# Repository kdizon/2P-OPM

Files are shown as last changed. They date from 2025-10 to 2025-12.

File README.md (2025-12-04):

# 2P-OPM: Two-photon oblique plane microscope

Open CAD, control code, reconstruction, data, and videos for the 2P-OPM instrument.

## Contents
- Opto-mechanical CAD (Inventor + STEP/STL): **[CAD/](./CAD)**
- Instrument control/acquisition (FastMC): **[code/control/](./code/control)**
- GPU-accelerated volume reconstruction: **[code/reconstruction/](./code/reconstruction)**
- Representative image datasets: **[data/](./data)**
- Associated videos: **[movies/](./movies)**

## Citation
If you use the 2P-OPM hardware design, code, data, or videos, please cite:

K. Keomanee-Dizon, Y. Clenman, A. Duran, S. Ryabichko, P. Hansen, T. Borjigin, R. Thornton, J. E. Toettcher, & H. M. McNamara.  
**Depth-enhanced molecular imaging with two-photon oblique plane microscopy.**  
arXiv:2511.09462 [physics.optics] (2025). https://doi.org/10.48550/arXiv.2511.09462

## Licensing
- Code: [BSD-3-Clause](./LICENSE)
- CAD: [CERN-OHL-P v2.0](./CAD/LICENSE)
- Data: [CC BY 4.0](./data/LICENSE)
- Videos: [CC BY 4.0](./movies/LICENSE)

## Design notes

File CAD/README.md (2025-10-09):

# 2P-OPM hardware
Hardware files for the 2P-OPM.

## Description
This repository contains the opto-mechanical CAD (AutoDesk Inventor) model for the 2P-OPM system. Files are organized in directories for each vendor, with subassemblies for various parts of the microscope.

© 2025 Kevin Keomanee-Dizon. Licensed under CERN-OHL-P v2.0; see [LICENSE](./LICENSE).

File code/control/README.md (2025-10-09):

# FastMC — Fast multi-camera acquisition for 2P-OPM

FastMC provides NI-DAQ–driven timing for one or more PCO Edge cameras (validated with up to 3), the OPM galvo, and optional LED control, with Micro-Manager used as the **viewer only**. The hardware timing and limits come from `FastMC_core.py`; `FastMC.py` is the user-editable runner/config.

---

## Files
- **`FastMC_core.py`** — core NI-DAQ functions and timing logic (galvo AO, LED DO, camera triggers, limits). _Do not modify._
- **`FastMC.py`** — edit parameters here (2D/3D, exposure, ROI, z-range, LED mode) and run.

## Requirements
- Windows with **NI-DAQmx** and a compatible NI device (e.g., Dev1).
- **PCO Edge** cameras (CL) with SDK/driver accessible to Python.
- Python packages: `nidaqmx`, `numpy`, `scipy`, `matplotlib`, `tkinter` (stdlib), and your PCO camera Python module (`pco`).  
- Micro-Manager (as a viewer only).

---

## Quick start
1. Open **`FastMC.py`** and set parameters (see inline comments):  
   - `multi_d=False` for **2D** (stacks = frames) **or** `True` for **3D** (stacks = volumes).  
   - `num_stacks`, `stack_delay_time`, `exposure_time`, `readout_mode="fast"|"slow"`.  
   - For 3D: set `z_start`, `z_end`, `z_step`.  
   - Optional LED control via `led_trigger="hardware"|"software_fraction"|"software_time"`, plus `led_stack_fraction_on` or `led_time_on`/`led_frequency`.
2. Run:
   ```bash
   python FastMC.py

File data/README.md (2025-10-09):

# Datasets (2P-OPM)

All datasets are **background-subtracted** and provided as **representative subsets**.

## Beads (PSF benchmarking)
- **Path:** `data/beads/Fig_S9/`
- **Type:** Reconstructed volume
- **File:** `recon_BS.tif`
- **Used in:** Fig. S9
- **Notes:** 0.08667 µm isotropic voxels

## Flies — dual-color transcription imaging
- **Path:** `data/flies/Fig_5a/`
- **Type:** Reconstructed volume (2 channels)
- **Files:**  
  `recon_bcd-eGFP_BS.tif`  
  `recon_hb-MS2-MCP-mCherry_BS.tif`
- **Used in:** Fig. 5a
- **Notes:** channels correspond to bcd-eGFP and hb-MS2/MCP-mCherry; 0.17334 µm isotropic voxels

## Flies — single-molecule imaging
- **Path:** `data/flies/Fig_5e-h/`
- **Type:** Raw single-molecule time lapse
- **File:** `Raw_BS.tif`
- **Used in:** Fig. 5e–h
- **Notes:** 0.17334 µm pixel size; 20 Hz frame rate

---

### Format
- **TIFF** stacks
- Acquisition & processing details are described in the manuscript (Methods and Imaging conditions).

© 2025 Kevin Keomanee-Dizon. Licensed under CC BY 4.0; see [LICENSE](./LICENSE).

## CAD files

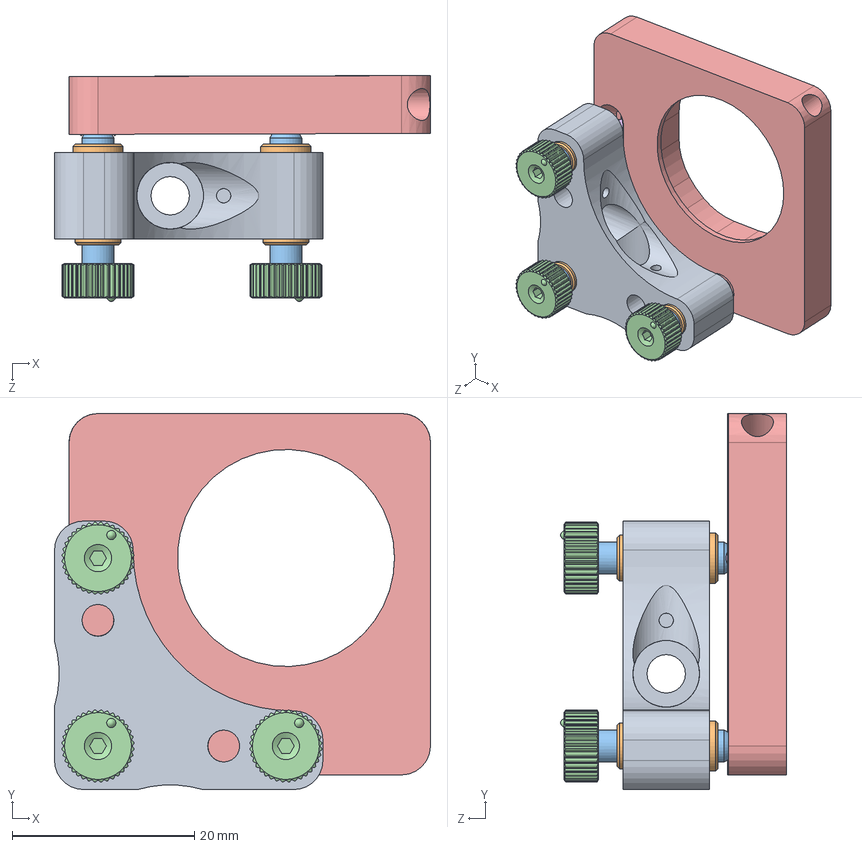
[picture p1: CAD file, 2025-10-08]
CAD/1P Laser Combiner/newfocus_9884_pint_size_corner_mount.sldasm
41.3 x 41.3 x 24.8 mm

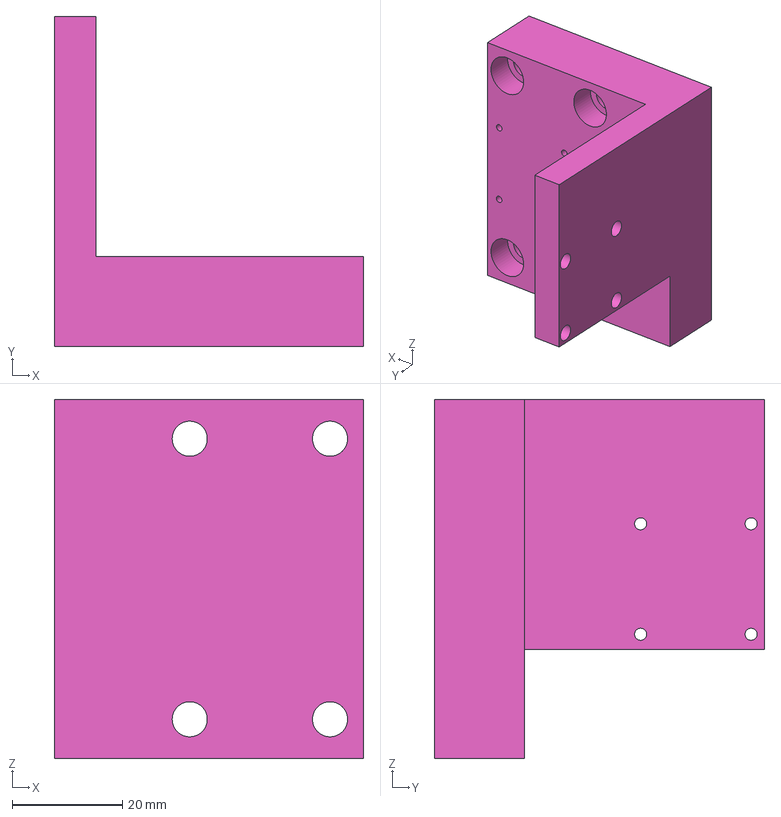
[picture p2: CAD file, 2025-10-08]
CAD/1P Laser Combiner/beam steering subassy mounting bracket.stp
56.0 x 59.8 x 65.0 mm

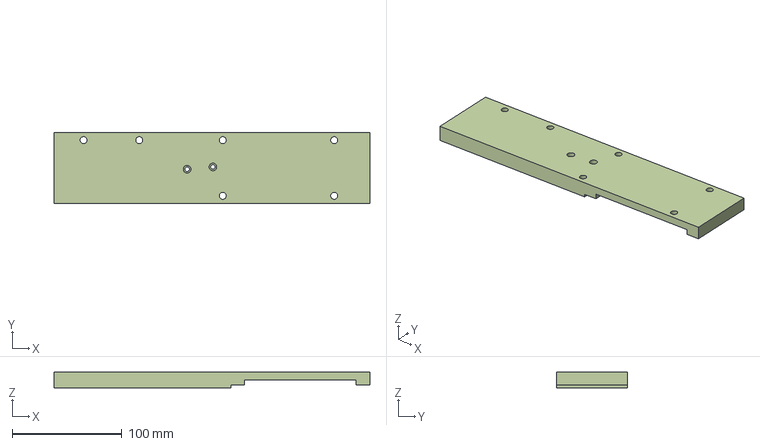
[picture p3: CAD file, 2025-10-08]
CAD/1P Laser Combiner/OBIS laser subassy shortened baseplate.stp
288.3 x 65.0 x 14.3 mm

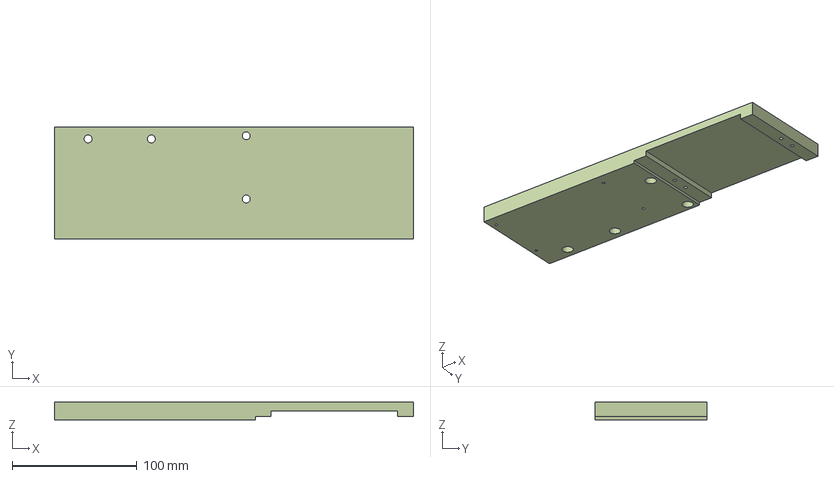
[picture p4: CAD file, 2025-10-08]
CAD/1P Laser Combiner/Sapphire laser subassy shortened baseplate.stp
288.3 x 90.0 x 14.3 mm

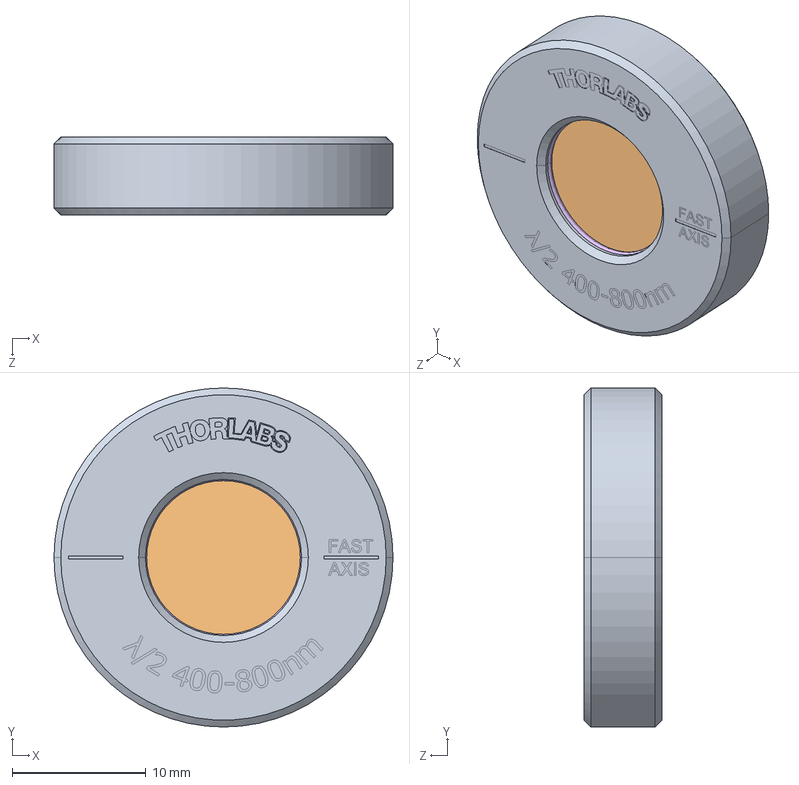
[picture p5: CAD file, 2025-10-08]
CAD/1P Laser Combiner/AHWP05M-600-Step.step
25.4 x 25.4 x 5.84 mm

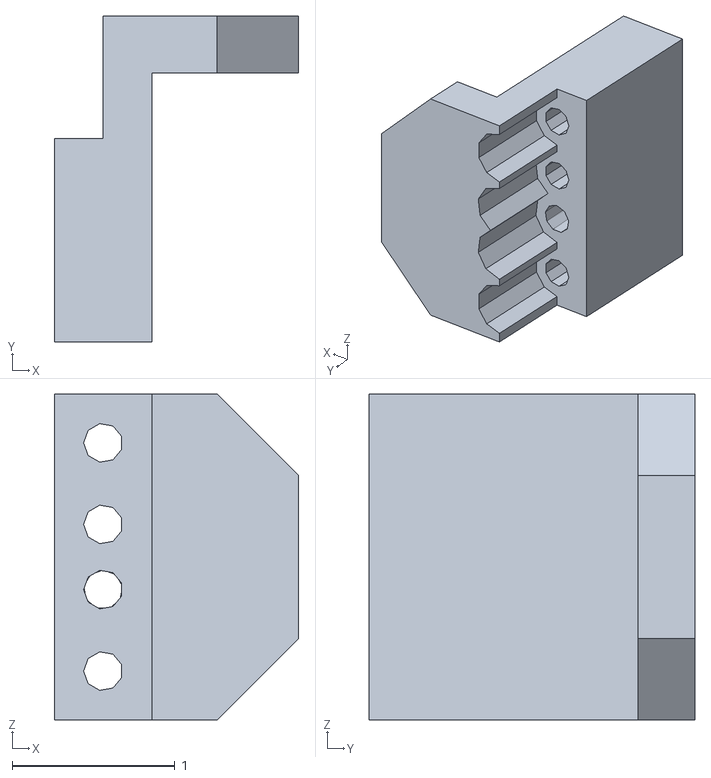
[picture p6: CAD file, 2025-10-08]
CAD/Custom 3D Printed Parts/galvo_stop.stl
1.50 x 2.00 x 2.00

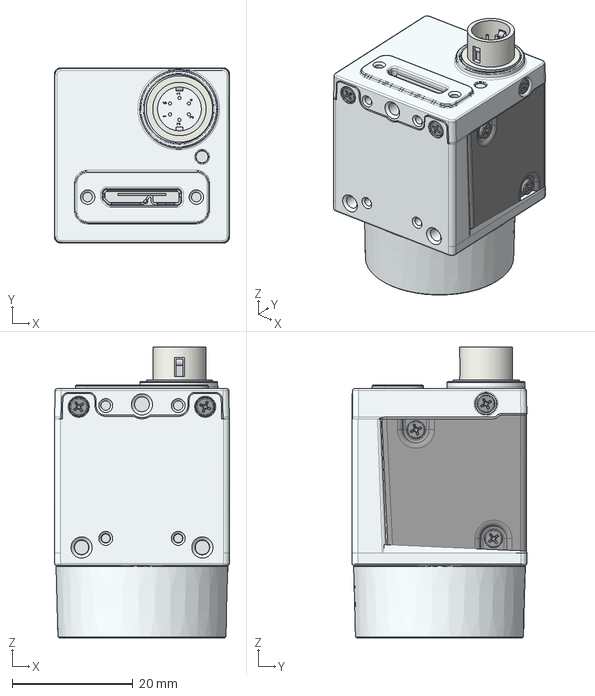
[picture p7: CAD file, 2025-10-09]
CAD/Imported Components/Basler/Basler ace USB3 C-Mount v02.STP
29.0 x 29.0 x 48.2 mm

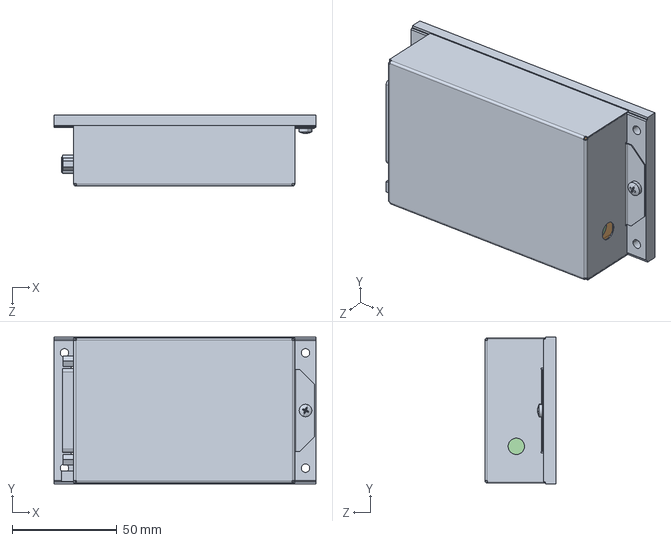
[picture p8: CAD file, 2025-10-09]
CAD/Imported Components/Coherent/Sapphire LP Laser Head.STEP
125.0 x 70.0 x 34.0 mm

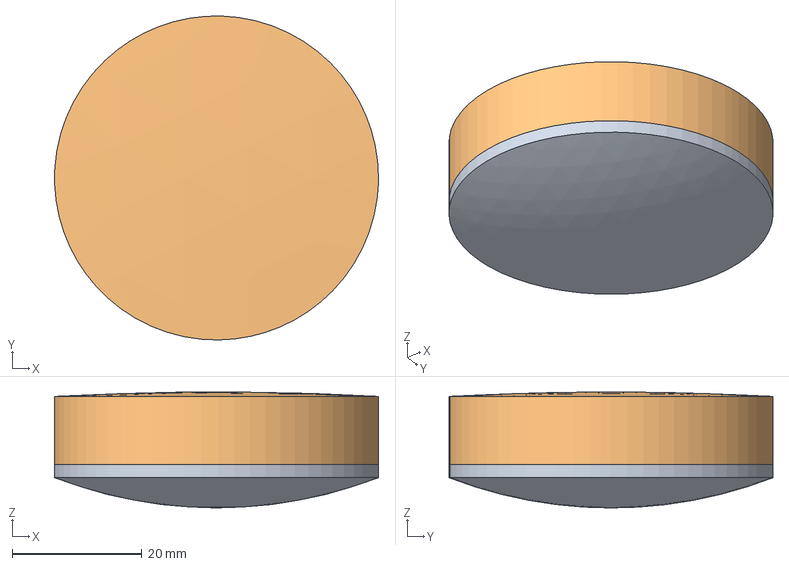
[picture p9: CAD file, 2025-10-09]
CAD/Imported Components/Edmund/EO_49390.stp
50.0 x 50.0 x 17.9 mm

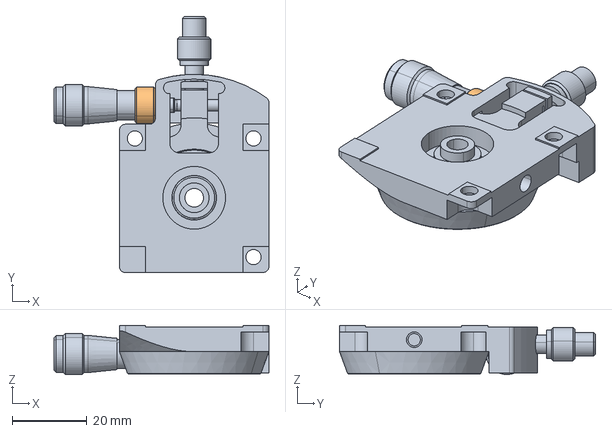
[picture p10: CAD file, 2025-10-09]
CAD/Imported Components/Newport/Newport-RS40.stp
57.5 x 68.5 x 13.1 mm

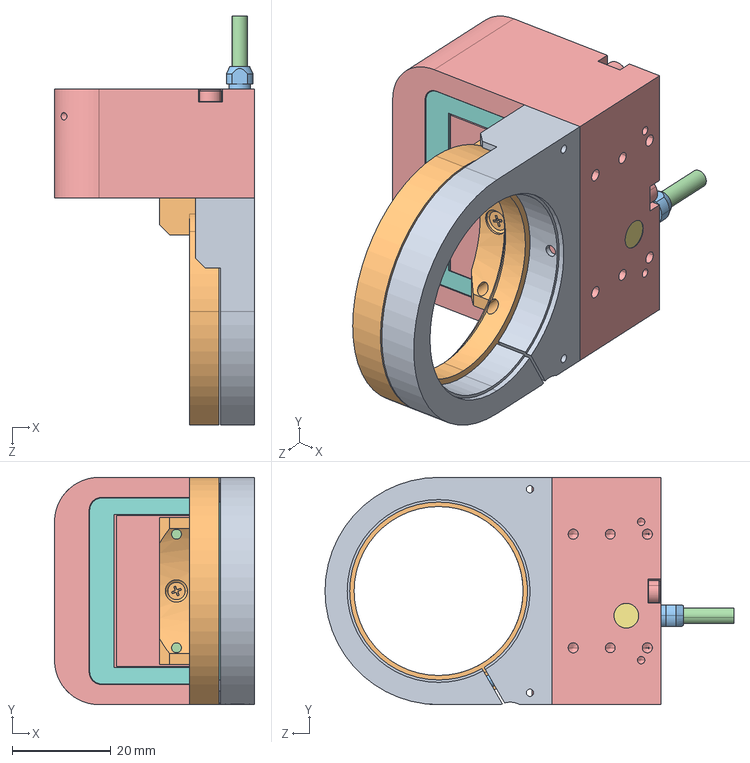
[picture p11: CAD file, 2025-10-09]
CAD/Imported Components/PI/P-725.xCA.STEP
40.5 x 46.0 x 82.8 mm

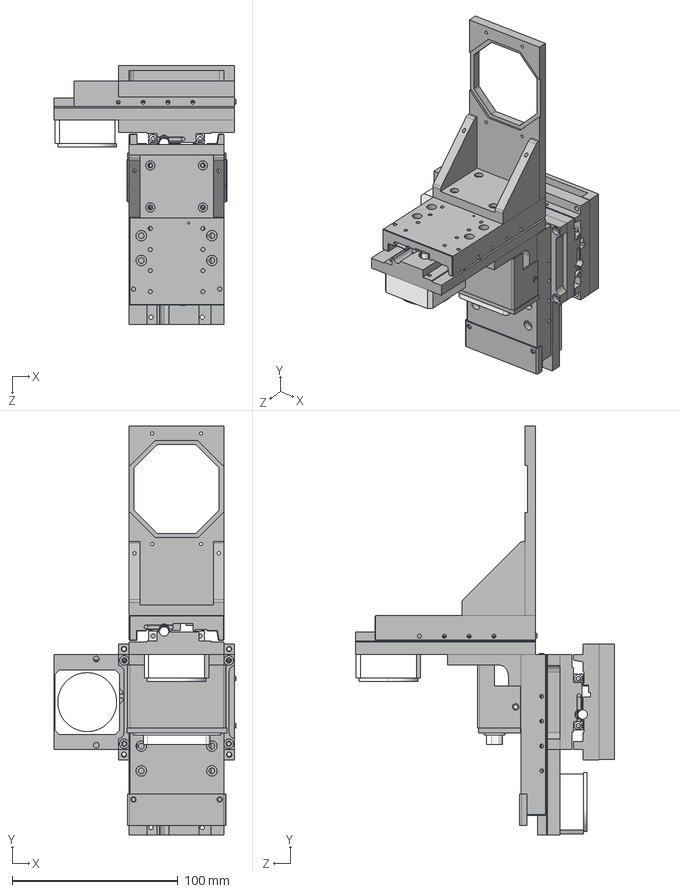
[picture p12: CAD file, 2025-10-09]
CAD/Imported Components/Sutter/MP285 3DMS SIMPLE.STEP
109.6 x 246.8 x 156.5 mm

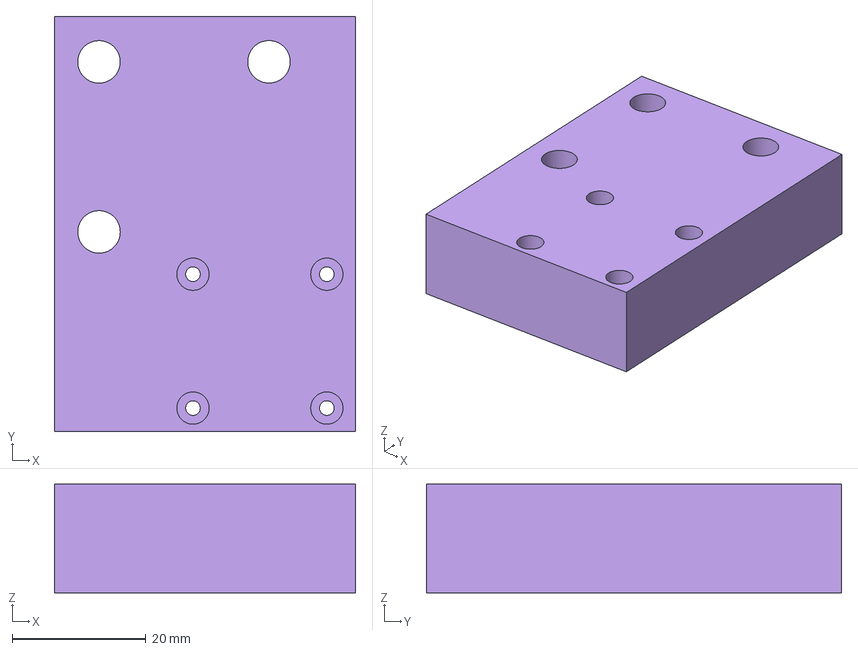
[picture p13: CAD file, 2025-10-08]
CAD/1P Laser Combiner/baseplate for combined beam steering mirror.stp
45.0 x 62.0 x 16.2 mm

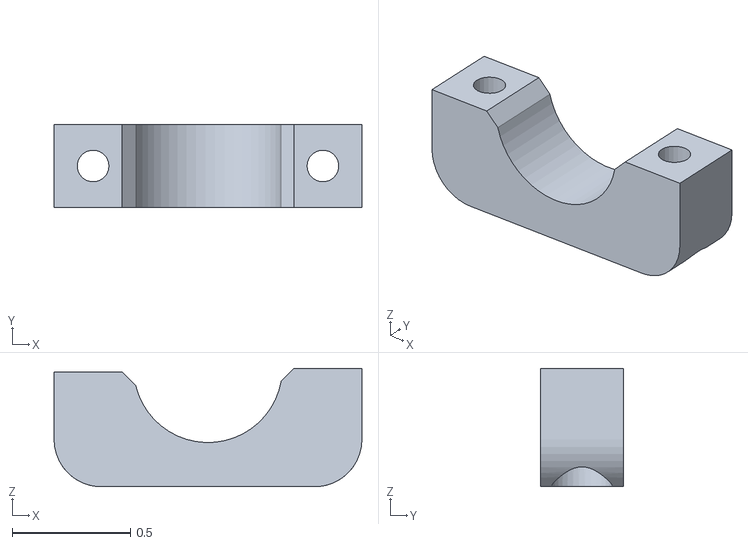
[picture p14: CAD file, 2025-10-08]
CAD/Custom 3D Printed Parts/20-1531-001_ResGalvoClamp.obj
1.30 x 0.35 x 0.5

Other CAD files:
CAD/Custom Parts Linked With Drawings/ResGalvoMount_base_plate.stp
CAD/Imported Components/Coherent/Sapphire LP Heatsink with dowel pins.STEP
CAD/Imported Components/Edmund/EO_85678.step
CAD/Imported Components/Newport/Newport-SA2-11.stp
CAD/1P Laser Combiner/003550_2.ipt
CAD/1P Laser Combiner/903279.ipt
CAD/1P Laser Combiner/903812-08.ipt
CAD/1P Laser Combiner/903893.ipt
CAD/1P Laser Combiner/903896.ipt
CAD/1P Laser Combiner/903898-01.ipt
CAD/1P Laser Combiner/9884PLT_ASM.iam
CAD/1P Laser Combiner/AA Optoelectronc AOTF-nc.ipt
CAD/1P Laser Combiner/AA Optoelectronc AOTF-nc.sldprt
CAD/1P Laser Combiner/AHWP05M-600-Step.ipt
CAD/1P Laser Combiner/Drawings/OBIS laser subassy shortened baseplate.idw
CAD/1P Laser Combiner/Drawings/Sapphire laser subassy shortened baseplate.idw
CAD/1P Laser Combiner/Drawings/baseplate for combined beam steering mirror.idw
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

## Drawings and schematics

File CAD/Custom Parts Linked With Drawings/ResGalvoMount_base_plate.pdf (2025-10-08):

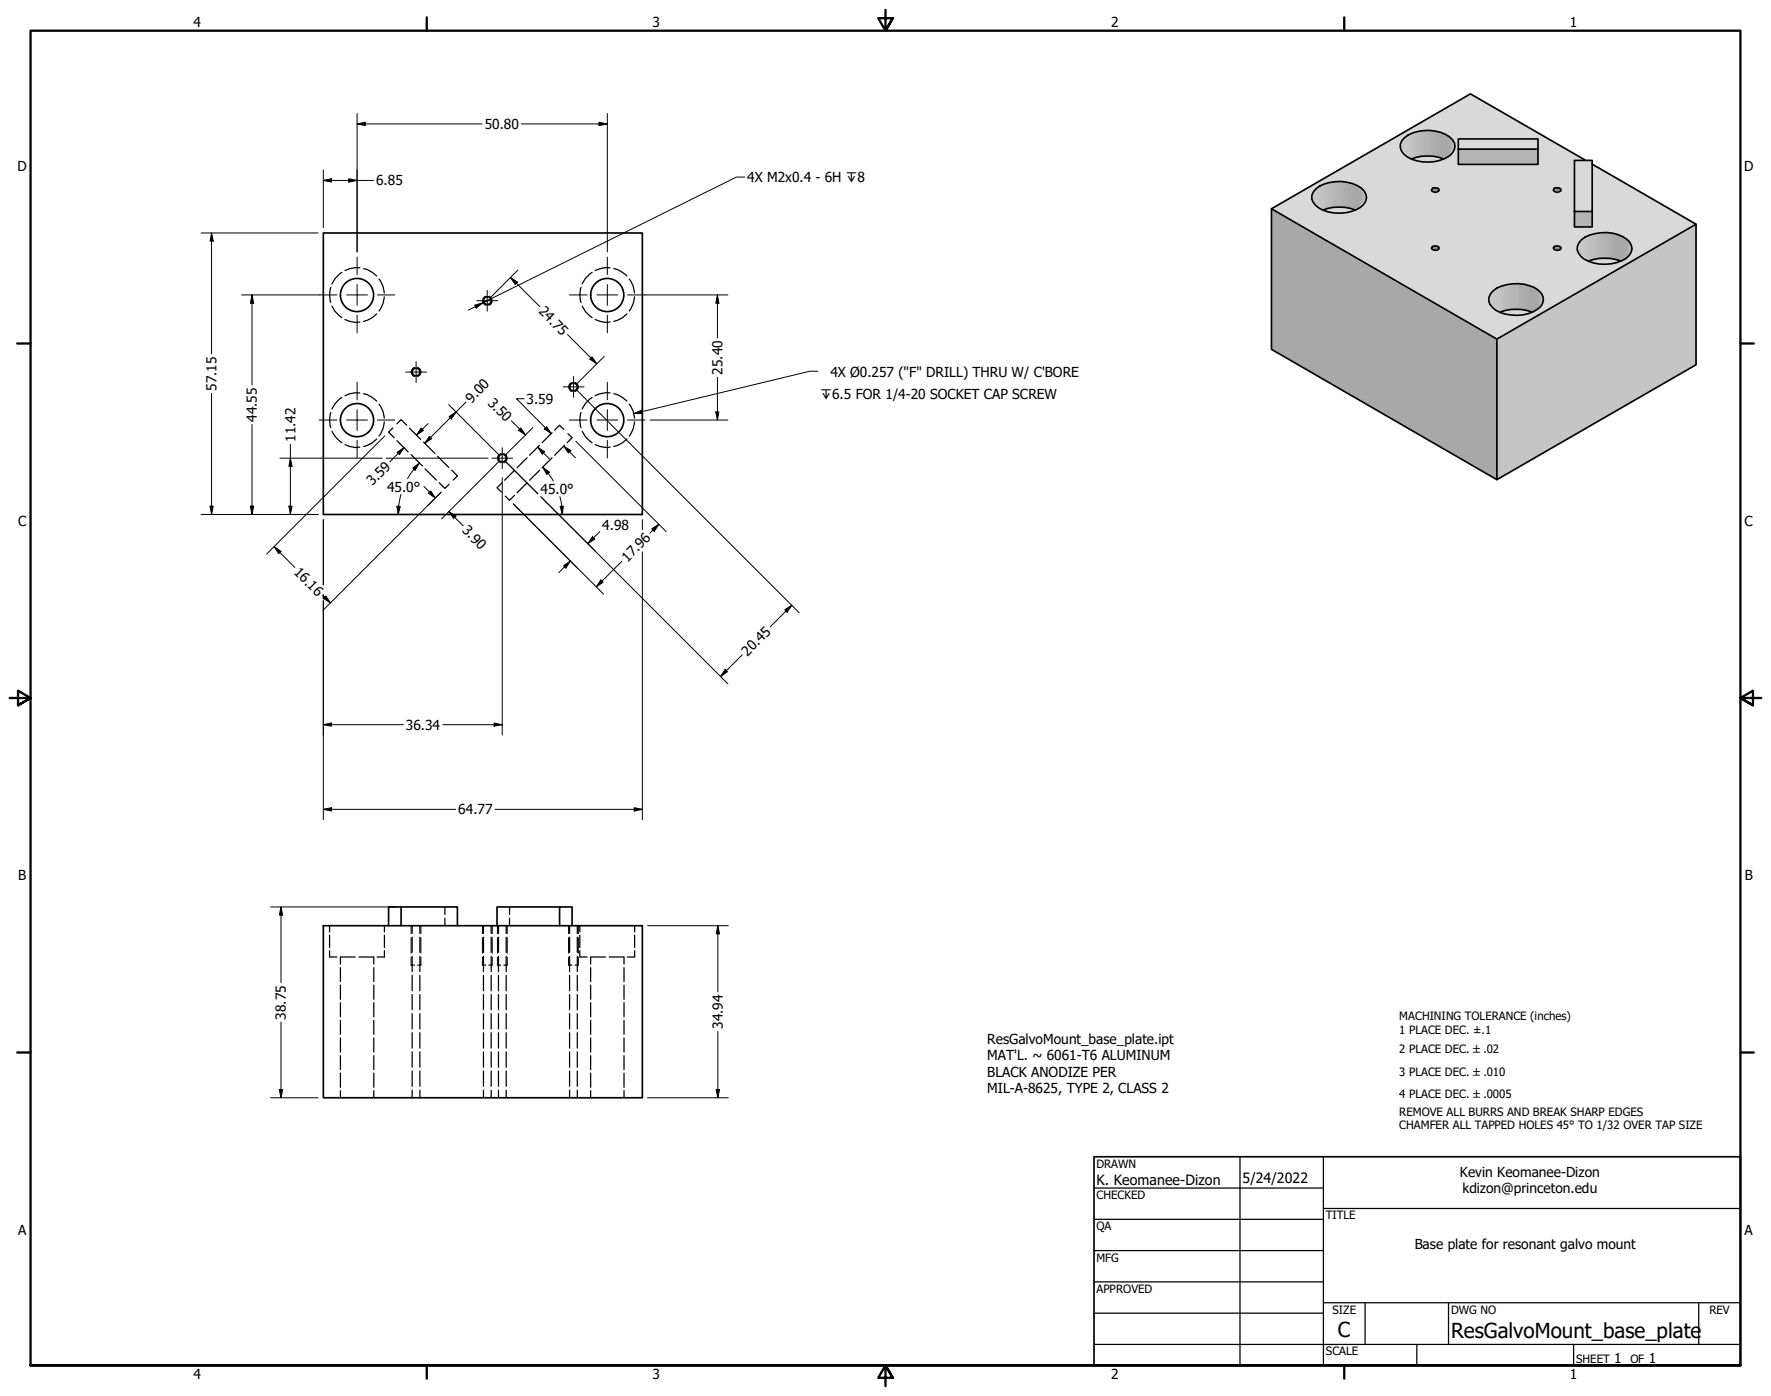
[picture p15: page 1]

4X Ø0.257 ("F" DRILL) THRU W/ C'BORE
6.5 FOR 1/4-20 SOCKET CAP SCREW

MACHINING TOLERANCE (inches)
1 PLACE DEC. ±.1
2 PLACE DEC. .02

ResGalvoMount_base_plate.ipt
MAT'L. ~ 6061-T6 ALUMINUM
BLACK ANODIZE PER
MIL-A-8625, TYPE 2, CLASS 2

4 PLACE DEC. .0005
REMOVE ALL BURRS AND BREAK SHARP EDGES
CHAMFER ALL TAPPED HOLES 45° TO 1/32 OVER TAP SIZE

DRAWN K. Keomanee-Dizon | 5/24/2022 | Kevin Keomanee-Dizon kdizon@princeton.edu

CHECKED

Base plate for resonant galvo mount

MFG

APPROVED

SIZE C | DWG NO ResGalvoMount_base_plate | REV

SCALE | | SHEET 1 OF 1

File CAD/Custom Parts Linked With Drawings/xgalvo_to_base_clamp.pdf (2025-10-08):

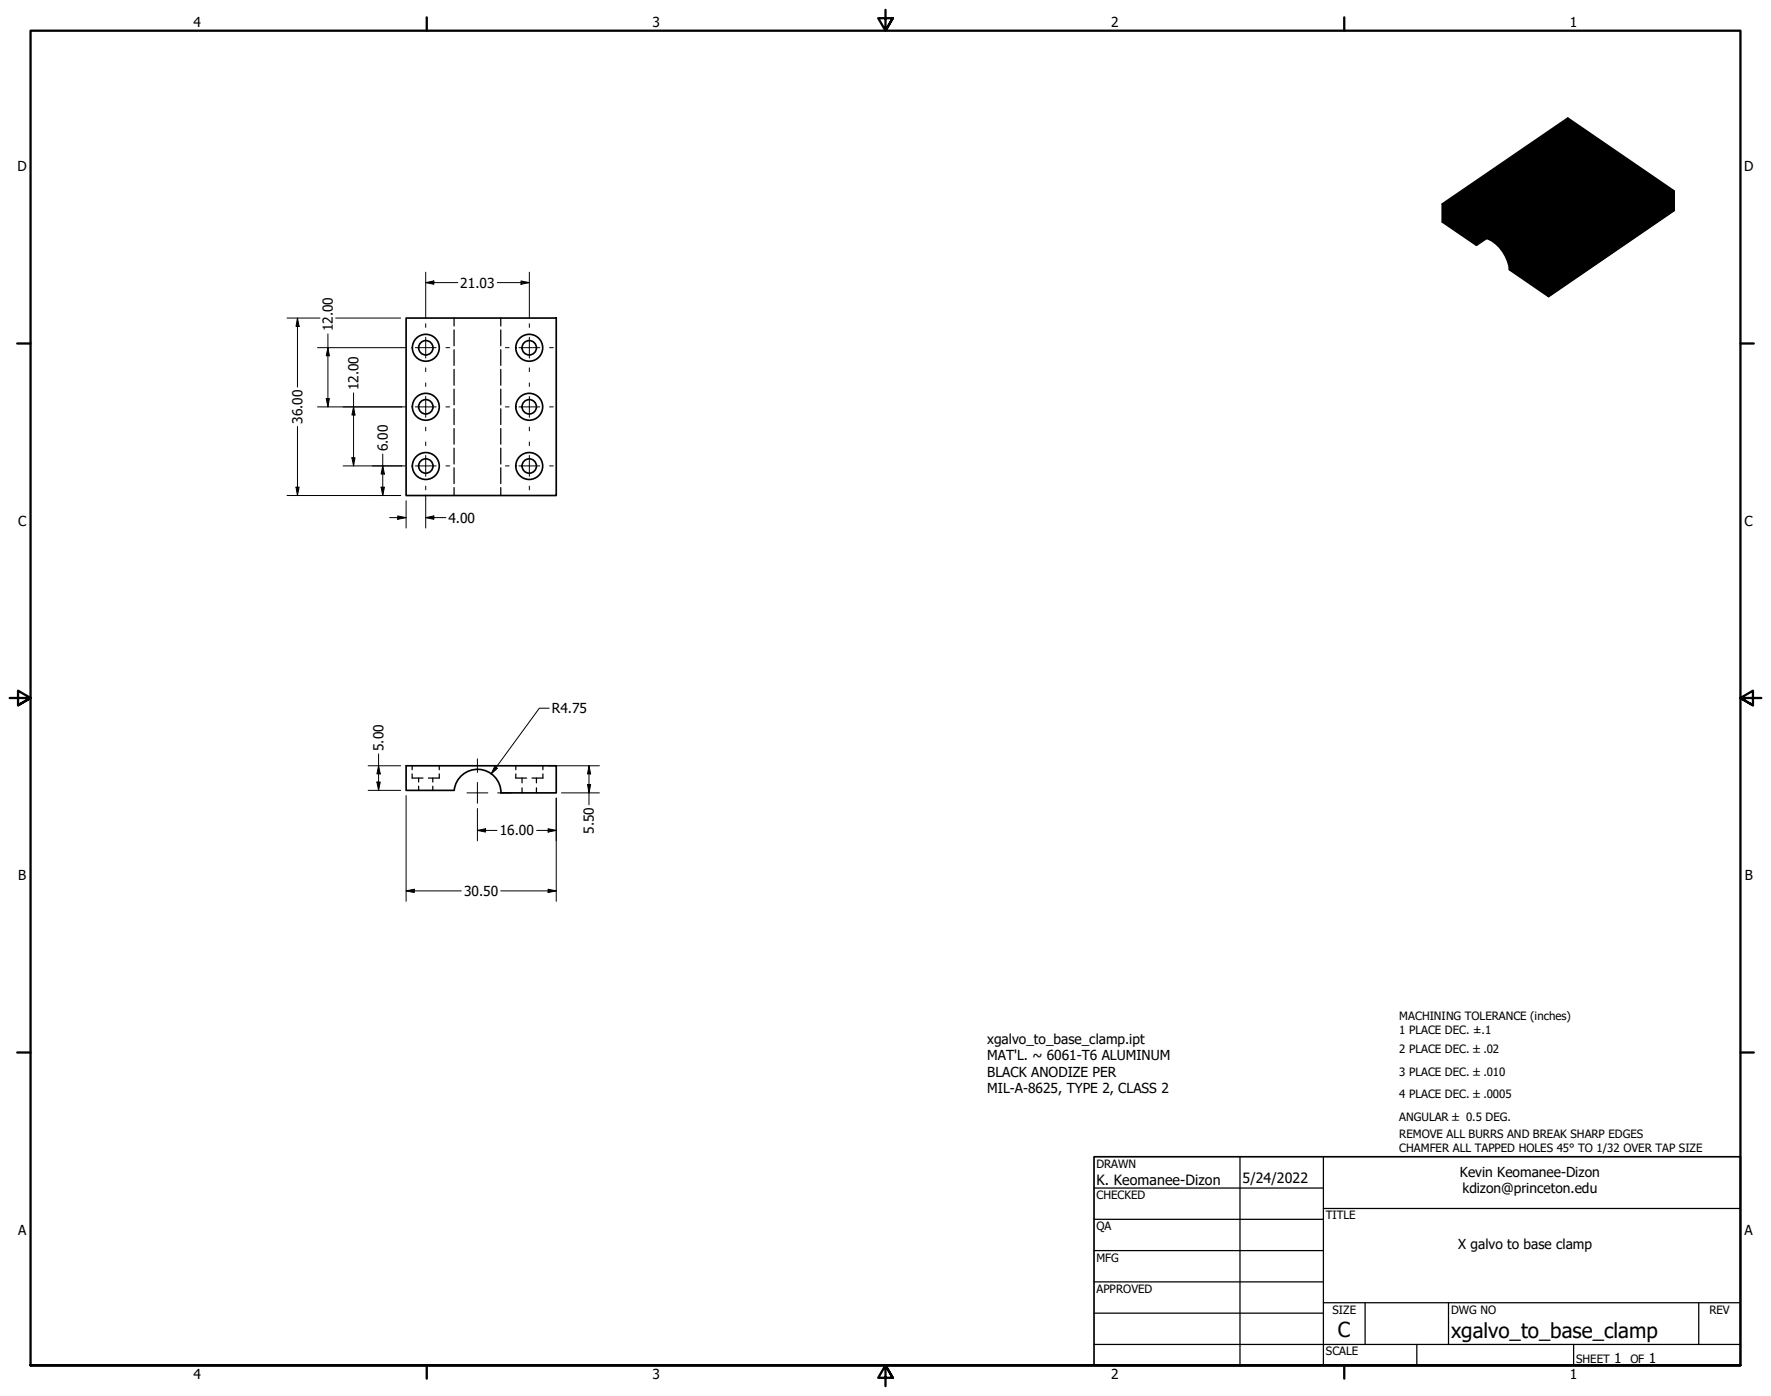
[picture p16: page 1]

MACHINING TOLERANCE (inches)
1 PLACE DEC. ±.1
2 PLACE DEC. .02

xgalvo_to_base_clamp.ipt
MAT'L. ~ 6061-T6 ALUMINUM
BLACK ANODIZE PER
MIL-A-8625, TYPE 2, CLASS 2

ANGULAR  0.5 DEG.
REMOVE ALL BURRS AND BREAK SHARP EDGES
CHAMFER ALL TAPPED HOLES 45° TO 1/32 OVER TAP SIZE

DRAWN K. Keomanee-Dizon | 5/24/2022 | Kevin Keomanee-Dizon kdizon@princeton.edu

CHECKED

X galvo to base clamp

MFG

APPROVED

SIZE C | DWG NO xgalvo_to_base_clamp | REV

SCALE | | SHEET 1 OF 1

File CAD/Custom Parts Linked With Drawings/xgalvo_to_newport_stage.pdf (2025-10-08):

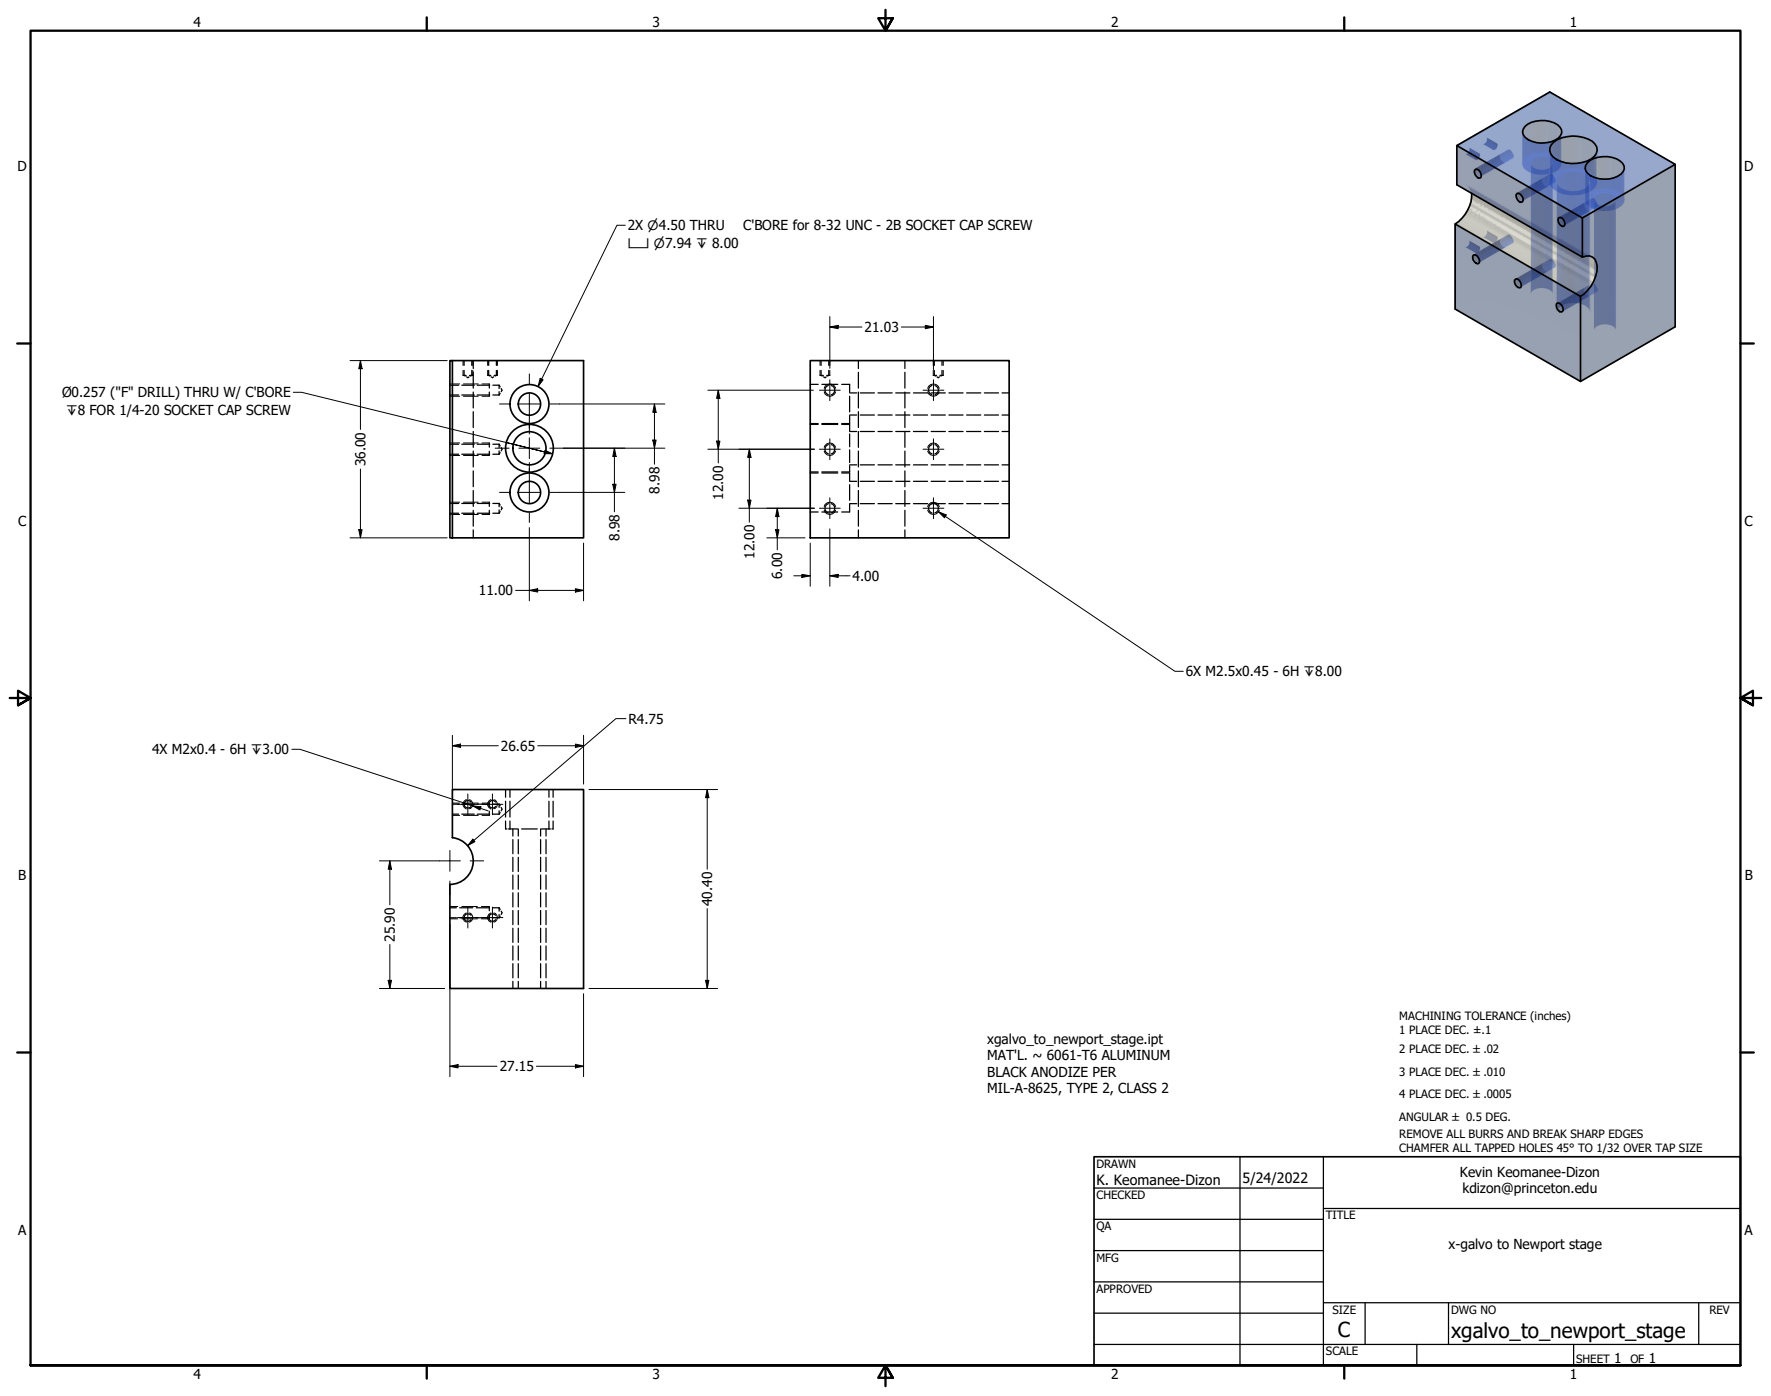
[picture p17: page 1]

C'BORE for 8-32 UNC - 2B SOCKET CAP SCREW

Ø0.257 ("F" DRILL) THRU W/ C'BORE
8 FOR 1/4-20 SOCKET CAP SCREW

MACHINING TOLERANCE (inches)
1 PLACE DEC. ±.1
2 PLACE DEC. .02

xgalvo_to_newport_stage.ipt
MAT'L. ~ 6061-T6 ALUMINUM
BLACK ANODIZE PER
MIL-A-8625, TYPE 2, CLASS 2

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

DRAWN K. Keomanee-Dizon | 5/24/2022 | Kevin Keomanee-Dizon kdizon@princeton.edu

CHECKED

x-galvo to Newport stage

MFG

APPROVED

SIZE C | DWG NO xgalvo_to_newport_stage | REV

SCALE | | SHEET 1 OF 1

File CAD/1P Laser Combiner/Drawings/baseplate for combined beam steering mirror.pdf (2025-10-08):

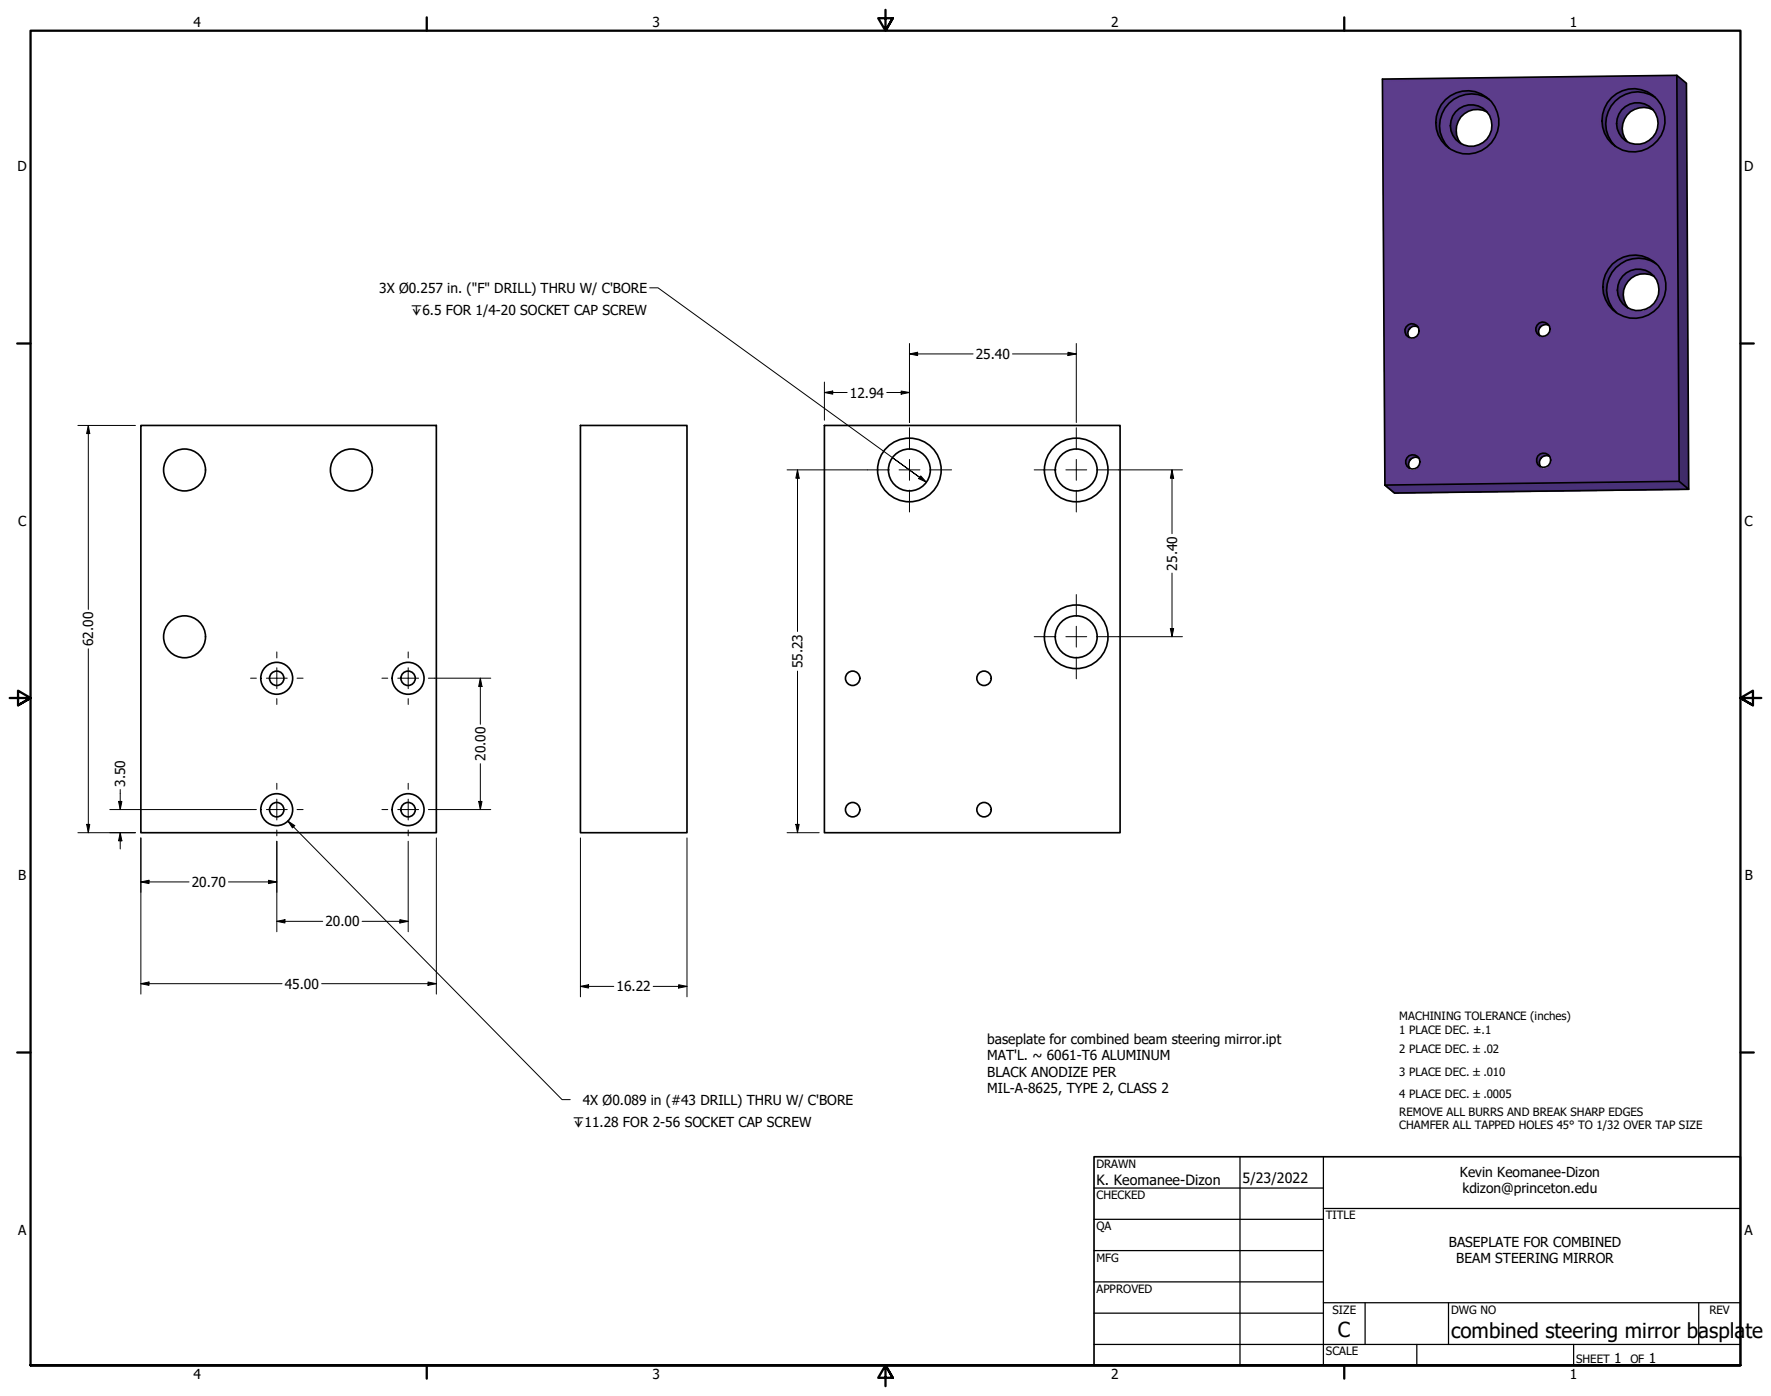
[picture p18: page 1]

3X Ø0.257 in. ("F" DRILL) THRU W/ C'BORE
6.5 FOR 1/4-20 SOCKET CAP SCREW

MACHINING TOLERANCE (inches)
1 PLACE DEC. ±.1
2 PLACE DEC. .02

baseplate for combined beam steering mirror.ipt
MAT'L. ~ 6061-T6 ALUMINUM
BLACK ANODIZE PER
MIL-A-8625, TYPE 2, CLASS 2

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

4X Ø0.089 in (#43 DRILL) THRU W/ C'BORE
11.28 FOR 2-56 SOCKET CAP SCREW

DRAWN K. Keomanee-Dizon | 5/23/2022 | Kevin Keomanee-Dizon kdizon@princeton.edu

CHECKED

BASEPLATE FOR COMBINED
BEAM STEERING MIRROR

MFG

APPROVED

SIZE C | DWG NO | REV

combined steering mirror basplate

SCALE | | SHEET 1 OF 1

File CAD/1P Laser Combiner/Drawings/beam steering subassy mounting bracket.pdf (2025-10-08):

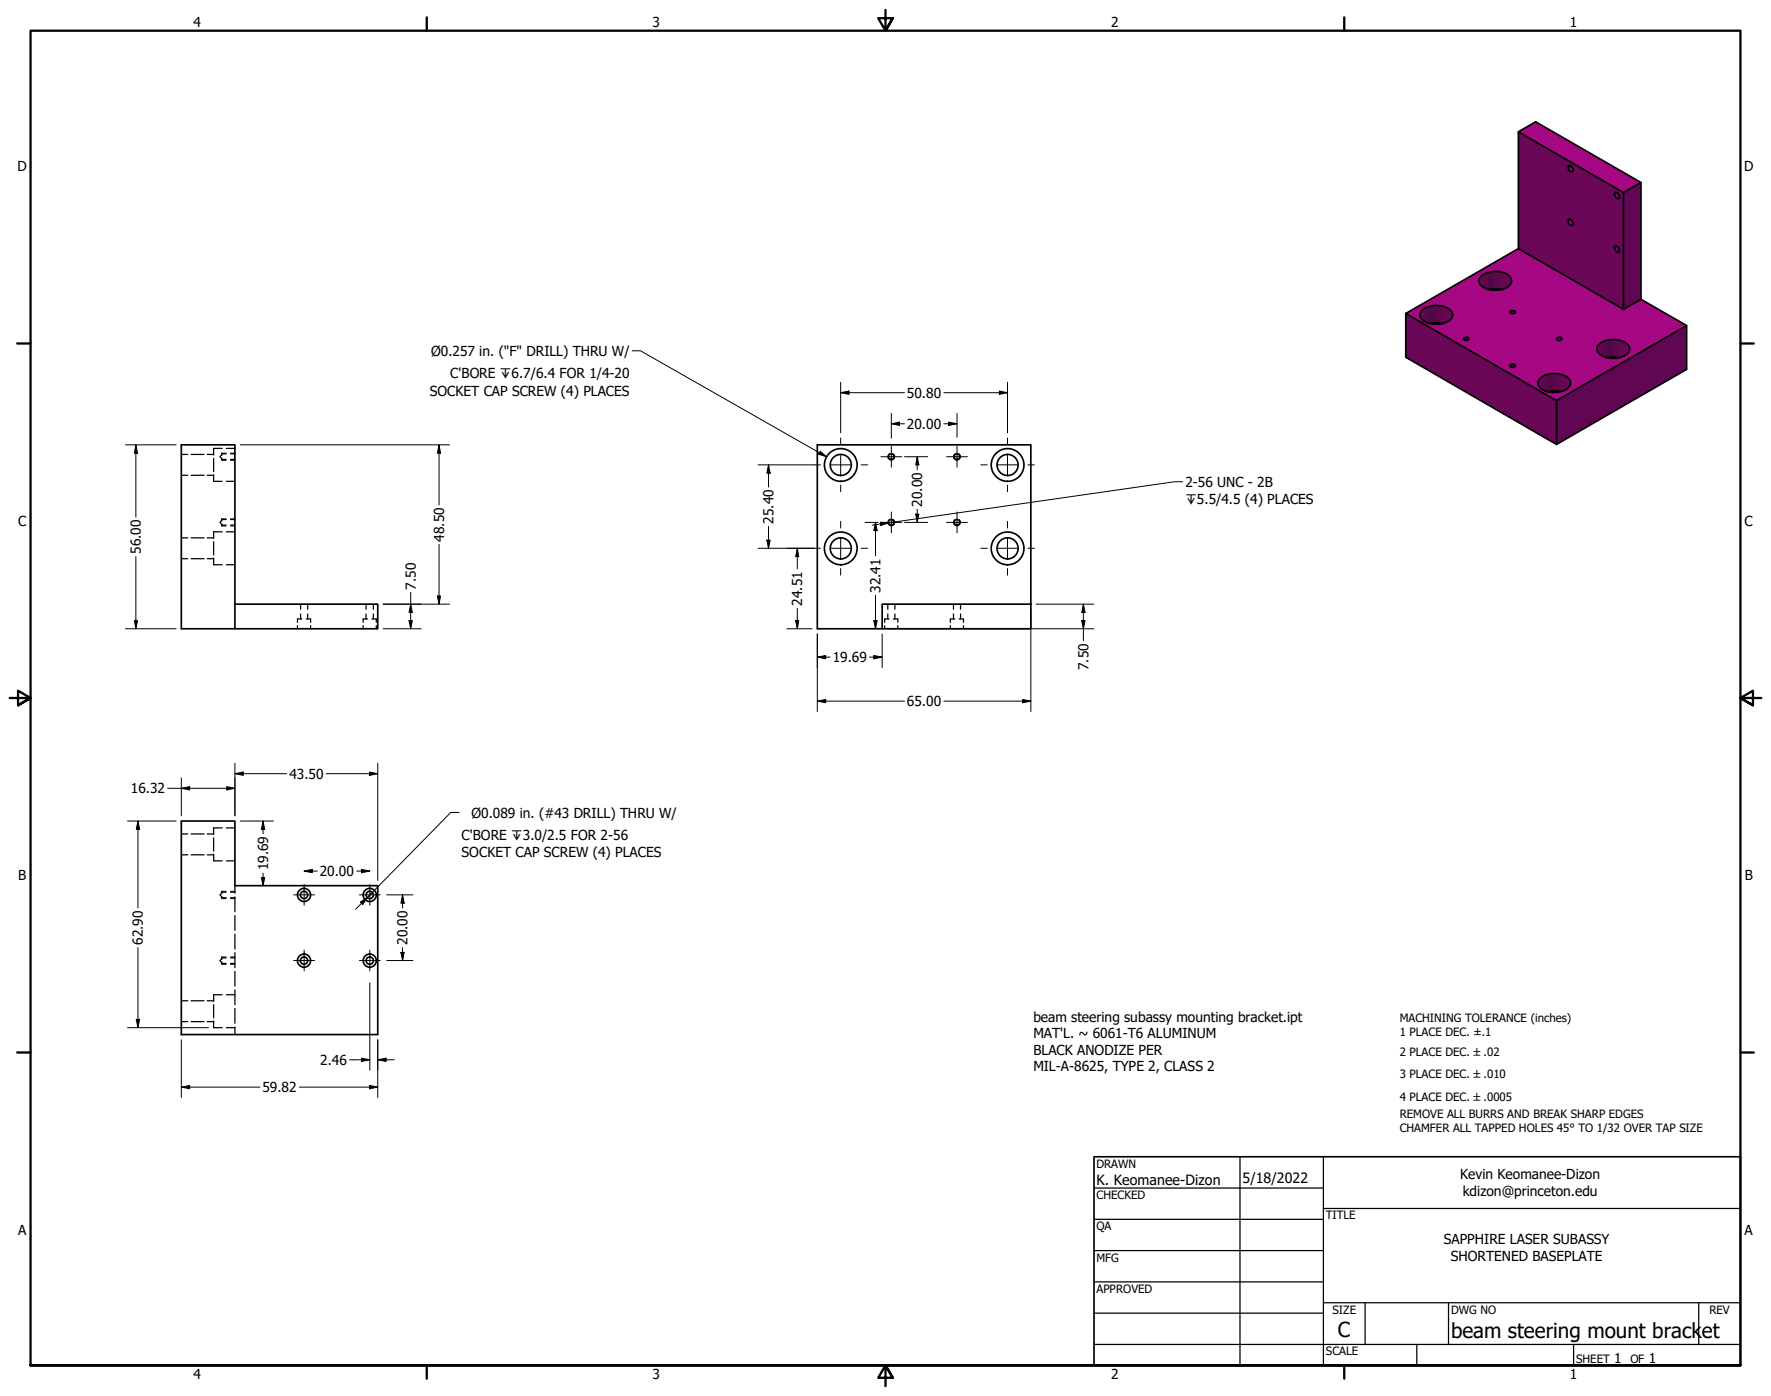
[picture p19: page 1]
2-56 UNC - 2B

Ø0.257 in. ("F" DRILL) THRU W/
C'BORE 6.7/6.4 FOR 1/4-20
SOCKET CAP SCREW (4) PLACES

Ø0.089 in. (#43 DRILL) THRU W/
C'BORE 3.0/2.5 FOR 2-56

beam steering subassy mounting bracket.ipt
MAT'L. ~ 6061-T6 ALUMINUM
BLACK ANODIZE PER
MIL-A-8625, TYPE 2, CLASS 2

MACHINING TOLERANCE (inches)
1 PLACE DEC. ±.1
2 PLACE DEC. .02

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

DRAWN K. Keomanee-Dizon | 5/18/2022 | Kevin Keomanee-Dizon kdizon@princeton.edu

CHECKED

SAPPHIRE LASER SUBASSY
SHORTENED BASEPLATE

MFG

APPROVED

SIZE C | DWG NO beam steering mount bracket | REV

SCALE | | SHEET 1 OF 1

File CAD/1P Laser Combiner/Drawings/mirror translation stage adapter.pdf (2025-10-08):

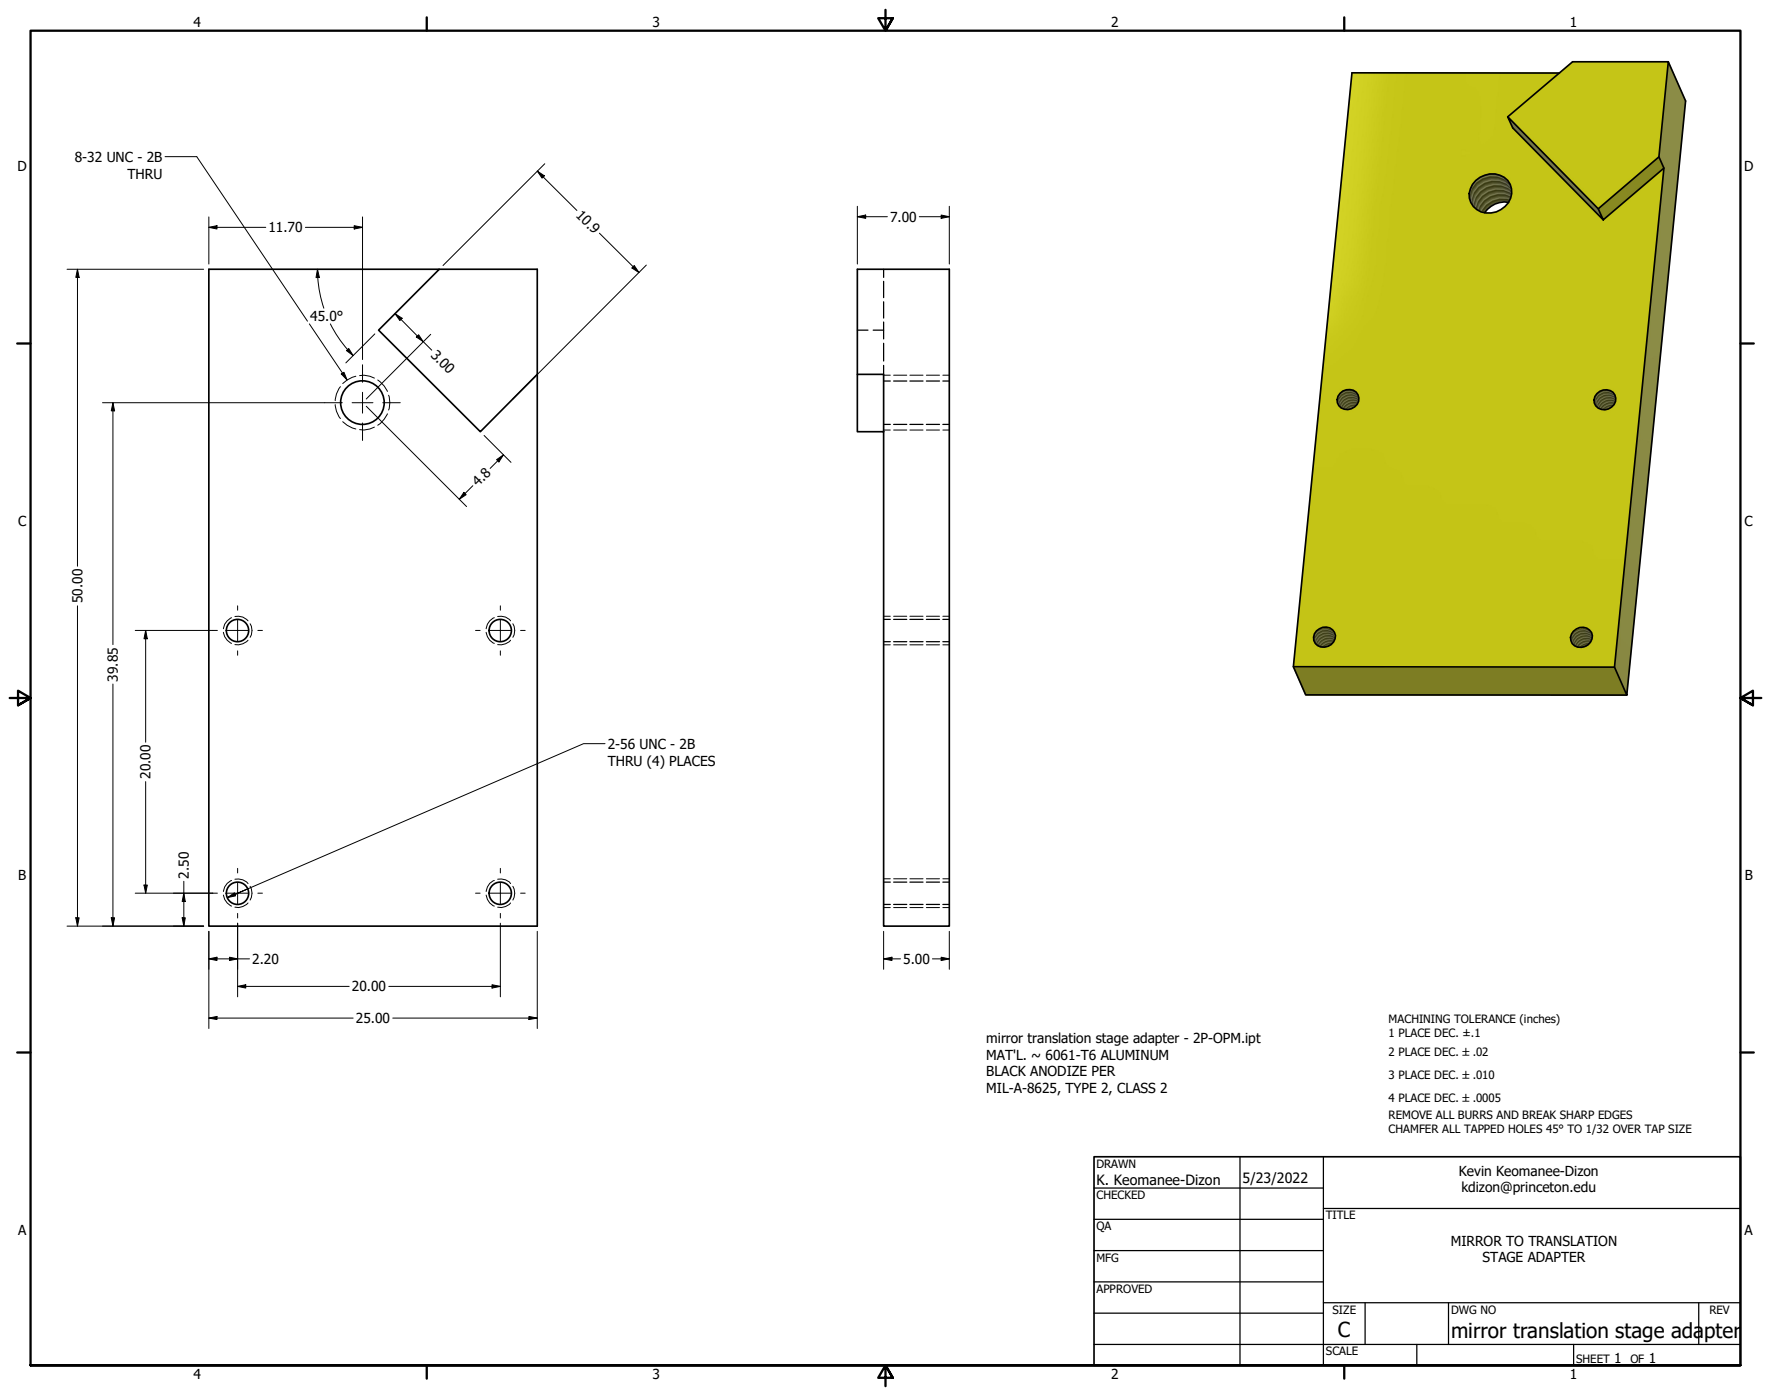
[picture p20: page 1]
2-56 UNC - 2B THRU (4) PLACES; 8-32 UNC - 2B

MACHINING TOLERANCE (inches)
1 PLACE DEC. ±.1
2 PLACE DEC. .02

mirror translation stage adapter - 2P-OPM.ipt
MAT'L. ~ 6061-T6 ALUMINUM
BLACK ANODIZE PER
MIL-A-8625, TYPE 2, CLASS 2

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

DRAWN K. Keomanee-Dizon | 5/23/2022 | Kevin Keomanee-Dizon kdizon@princeton.edu

CHECKED

MIRROR TO TRANSLATION
STAGE ADAPTER

MFG

APPROVED

SIZE C | DWG NO mirror translation stage adapter | REV

SCALE | | SHEET 1 OF 1

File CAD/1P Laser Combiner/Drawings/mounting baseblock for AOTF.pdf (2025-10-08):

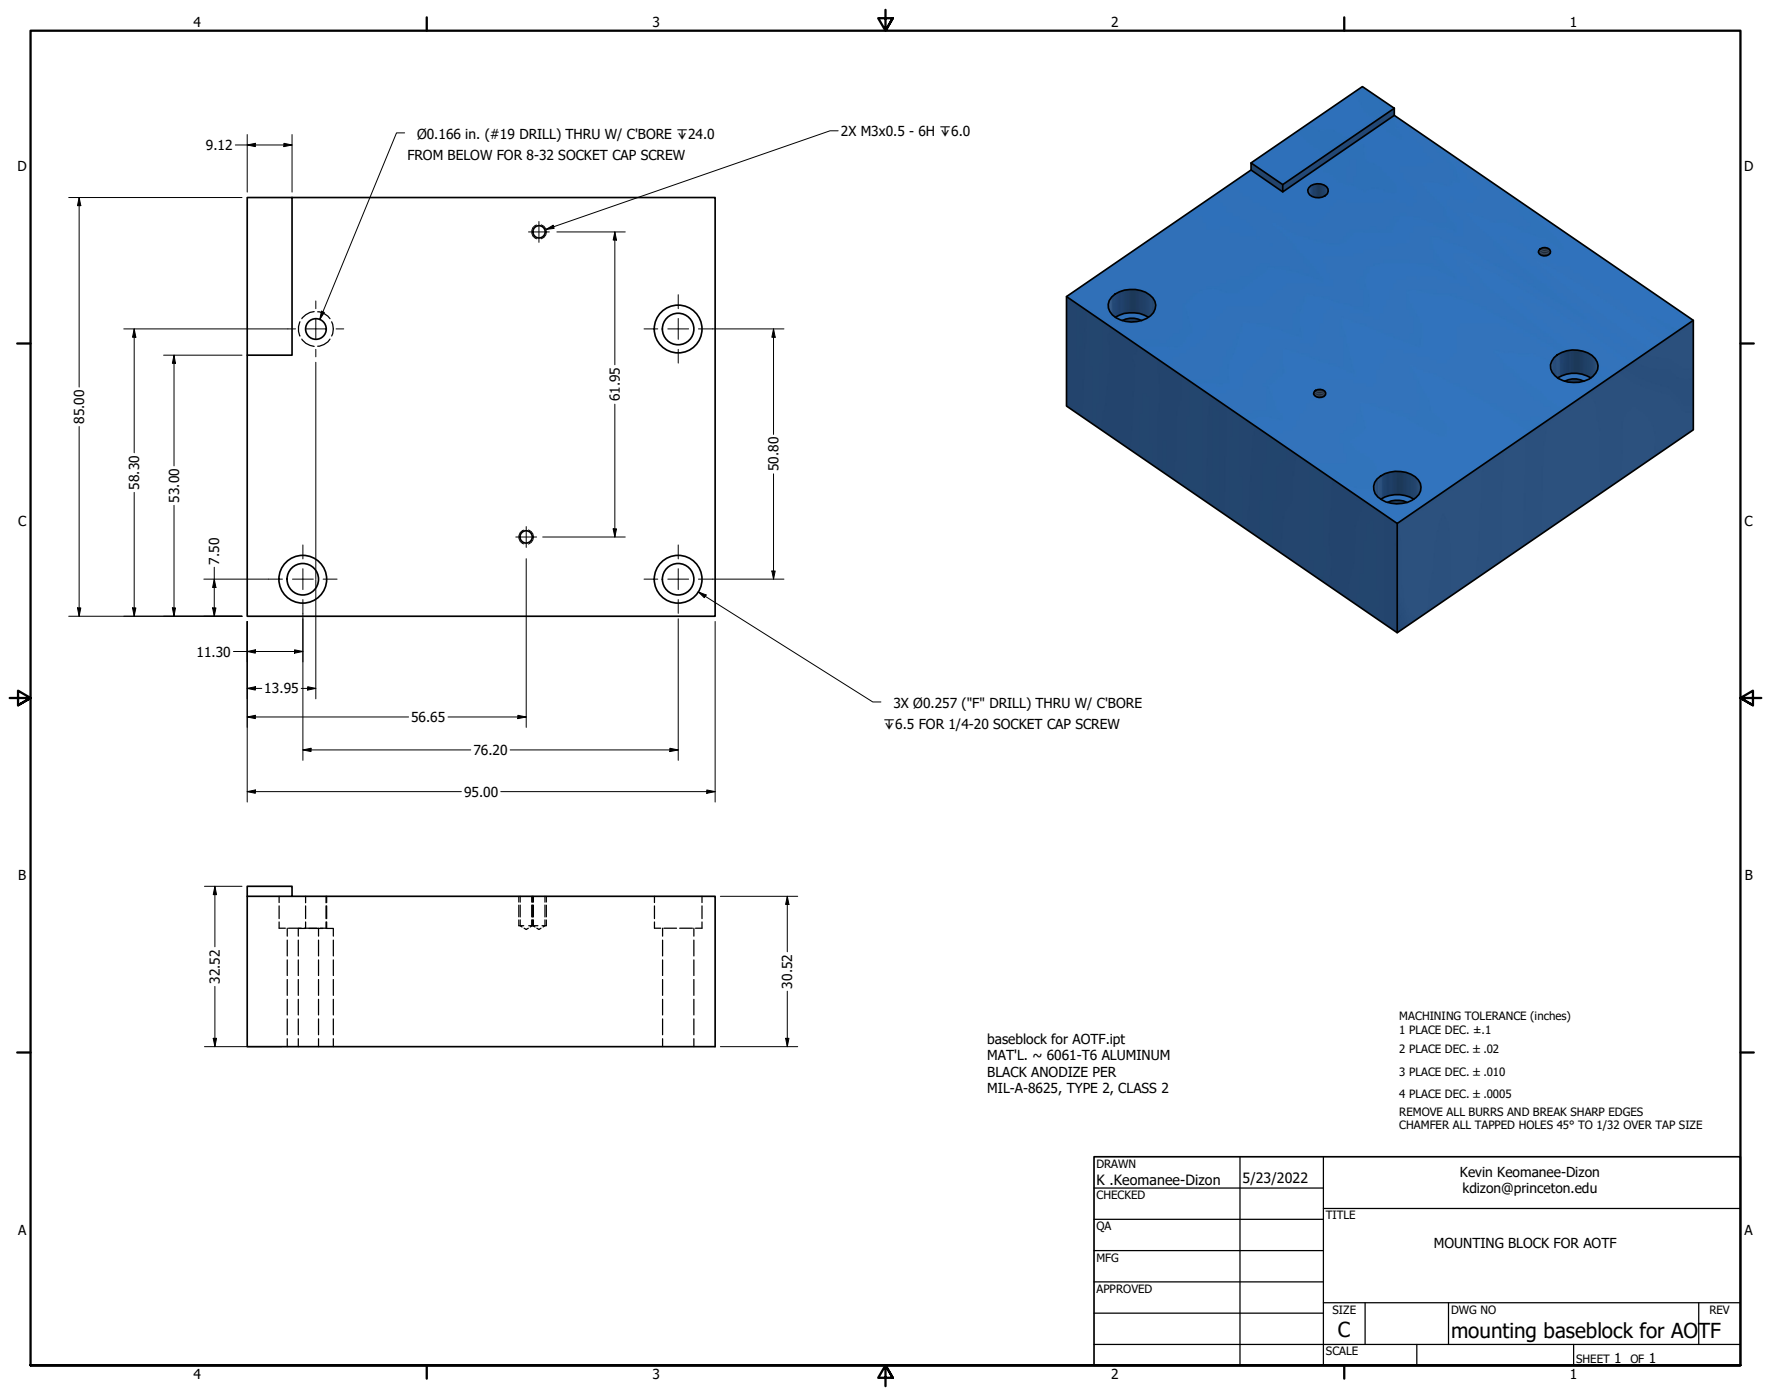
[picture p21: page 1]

FROM BELOW FOR 8-32 SOCKET CAP SCREW

3X Ø0.257 ("F" DRILL) THRU W/ C'BORE
6.5 FOR 1/4-20 SOCKET CAP SCREW

MACHINING TOLERANCE (inches)
1 PLACE DEC. ±.1
2 PLACE DEC. .02

baseblock for AOTF.ipt
MAT'L. ~ 6061-T6 ALUMINUM
BLACK ANODIZE PER
MIL-A-8625, TYPE 2, CLASS 2

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

DRAWN K .Keomanee-Dizon | 5/23/2022 | Kevin Keomanee-Dizon kdizon@princeton.edu

CHECKED

MOUNTING BLOCK FOR AOTF

MFG

APPROVED

SIZE C | DWG NO mounting baseblock for AOTF | REV

SCALE | | SHEET 1 OF 1

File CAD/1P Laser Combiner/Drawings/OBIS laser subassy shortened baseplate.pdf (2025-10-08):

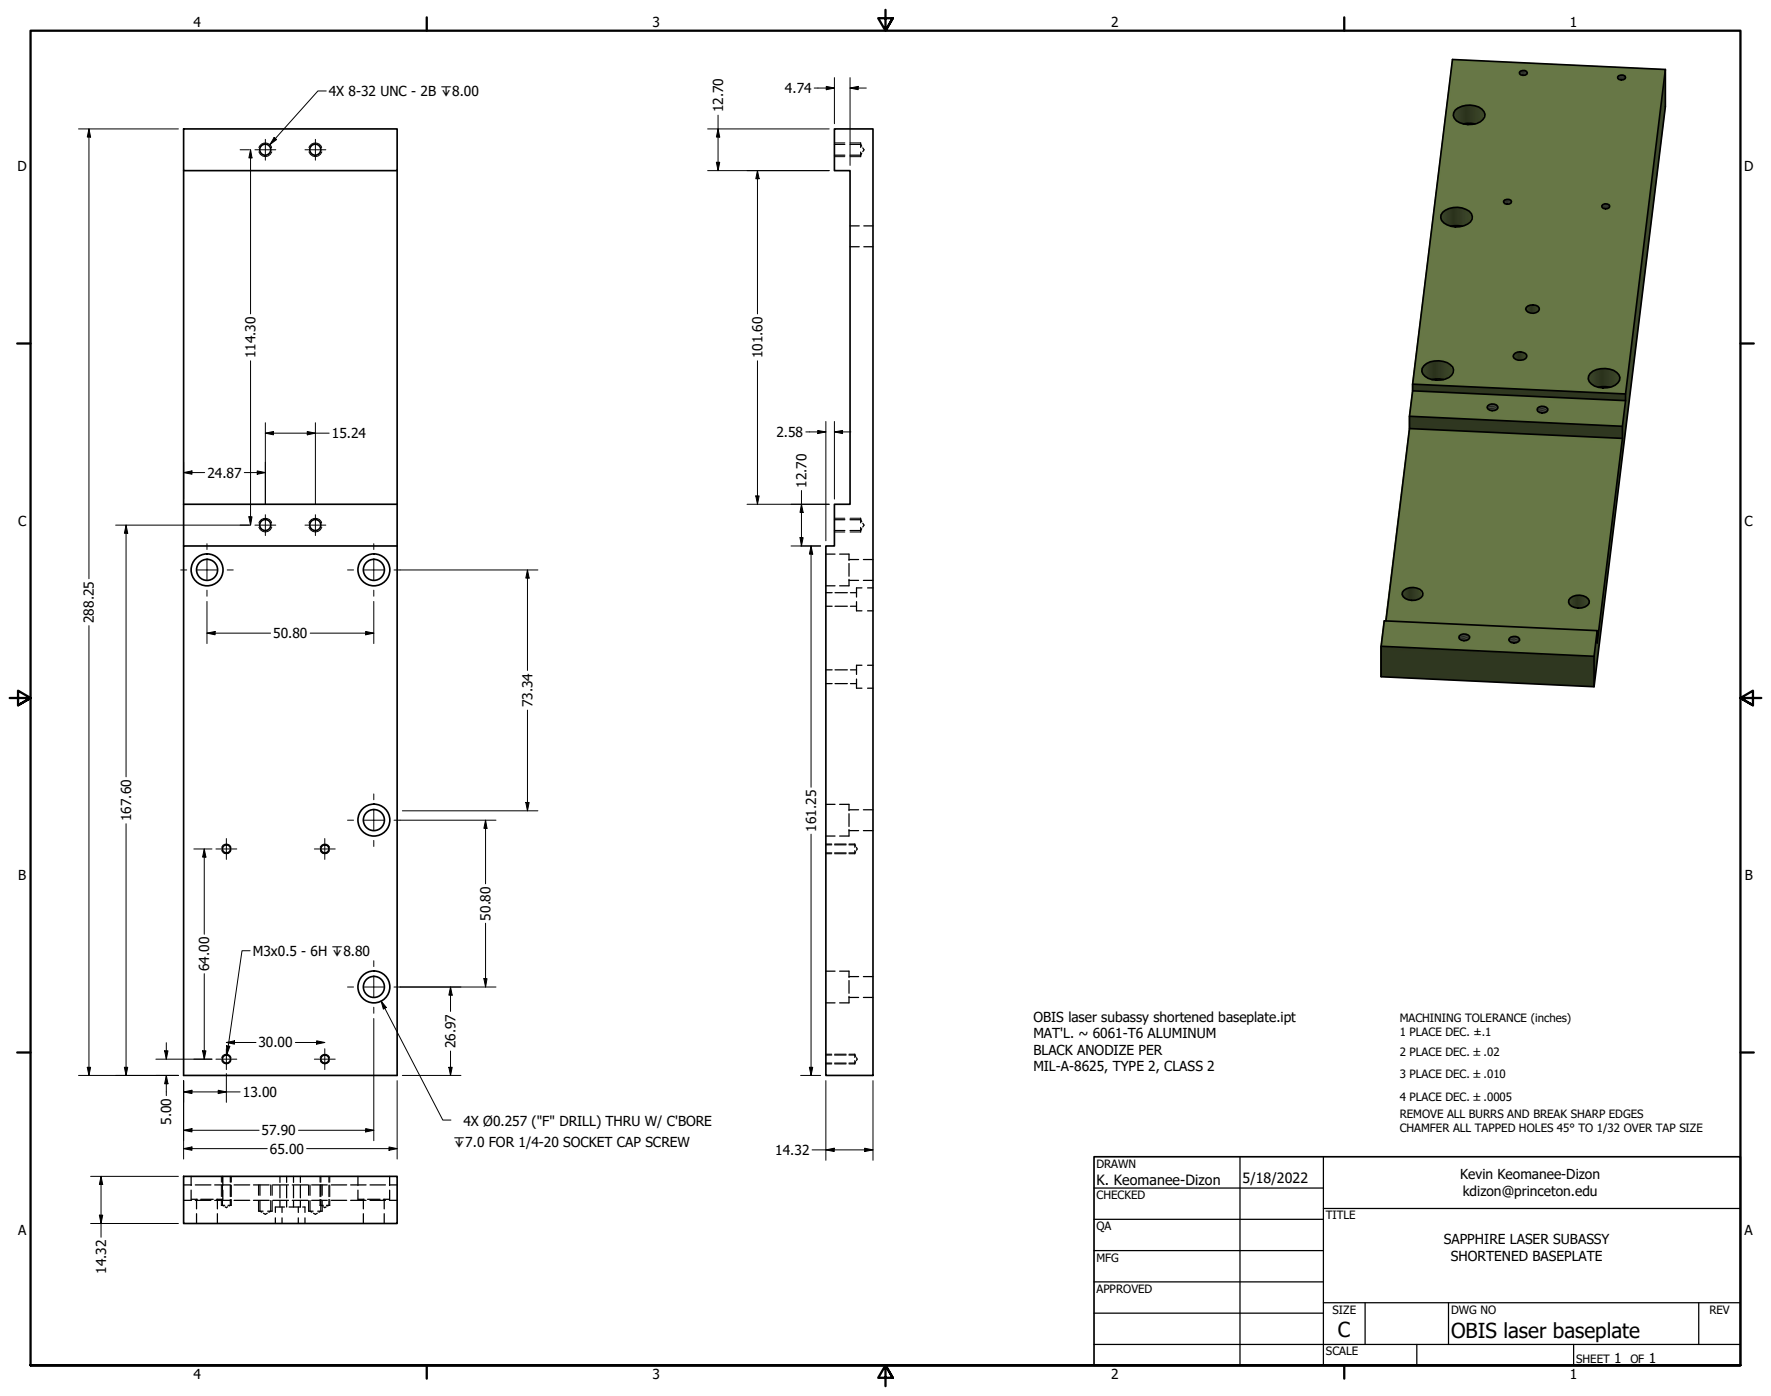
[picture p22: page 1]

OBIS laser subassy shortened baseplate.ipt
MAT'L. ~ 6061-T6 ALUMINUM
BLACK ANODIZE PER
MIL-A-8625, TYPE 2, CLASS 2

MACHINING TOLERANCE (inches)
1 PLACE DEC. ±.1
2 PLACE DEC. .02

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

4X Ø0.257 ("F" DRILL) THRU W/ C'BORE
7.0 FOR 1/4-20 SOCKET CAP SCREW

DRAWN K. Keomanee-Dizon | 5/18/2022 | Kevin Keomanee-Dizon kdizon@princeton.edu

CHECKED

SAPPHIRE LASER SUBASSY
SHORTENED BASEPLATE

MFG

APPROVED

SIZE C | DWG NO OBIS laser baseplate | REV

SCALE | | SHEET 1 OF 1

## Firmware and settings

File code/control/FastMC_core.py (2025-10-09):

# SPDX-License-Identifier: BSD-3-Clause


import nidaqmx
import nidaqmx.system
import numpy as np
import tkinter as tk
from tkinter import messagebox
import pco   
import matplotlib.pyplot as plt
import scipy
import math

# Create a workflow using the NI-DAQmx Python API to synchronize the 
# acquisition of a camera with the generation of an analog signal to control a 
# galvo mirror and digital signals to control 2 lasers (LED)

class nidaq:
    # Analog input/output only    
    ao0 = "Dev1/ao0"   # OPM galvo
    ao1 = "Dev1/ao1"   # AOTF / LED voltage modulator

    # trigger/counter
    ctr1 = "Dev1/ctr1"                     # camera exposure pulses
    ctr1_internal = "ctr1InternalOutput"   # idle
    ctr0 = "Dev1/ctr0"                     # stack trigger
    ctr0_internal = "ctr0InternalOutput"   # internal signal for stack trigger

    # programmable function I/O (PFI lines)
    PFI0 = "PFI0"
    PFI1 = "Dev1/PFI1"   

    # Digital and timing I/O (not all)
    do0 = "Dev1/port0/line0"   # LED
    do1 = "Dev1/port0/line1"   # 488
    do2 = "Dev1/port0/line2"   # 561

    # galvo GVS011
    MAXV_GALVO = 1.521
    MINV_GALVO = -1.521
    
    # AOTFnC-400.650-TN
    MIN_RF = 74e6         # Hz
    MAX_RF = 158e6        # Hz
    MAX_RF_POWER = 0.15   # Watts

    # pco 4.2 CL
    LINE_TIME_SLOW = 27.77e-6     # sec
    LINE_TIME_FAST = 9.76e-6      # sec
    READOUT_RATE_SLOW = 95.3e6    # px/sec
    READOUT_RATE_FAST = 272.3e6   # px/sec
    MAX_FRAME_RATE_SLOW = 35      # fps
    MAX_FRAME_RATE_FAST = 100     # fps
    SYS_DELAY = 2.99e-6           # sec MEASURED 
    JITTER = 0.3e-6               # sec MEASURED
    MIN_EXP = 100e-6              # sec
    MAX_EXP = 10.0                # sec
    MAX_DELAY = 1.0               # sec
    MIN_WIDTH = 40                # px
    MAX_WIDTH = 2060              # px
    MIN_HEIGHT = 16               # px
    MAX_HEIGHT = 2048             # px

    def __init__(
            self, 
            num_stacks: int,                # number of 3D stacks if multi d, number of frames if not
            stack_delay_time: float,        # s. time between acquiring any 2 stacks 
            exposure_time: float,           # s. effective exposure will be less due to system delay
            readout_mode: str,              # camera readout mode "fast" or "slow"
            multi_d: bool,                  # multidimensional acquisition
            z_start = 0.0,                  # microm. start of z stack. min -200
            z_end = 0.0,                    # microm. end of z stack. max 200
            z_step = 0.0,                   # microm. Step size of galvo scanning
            image_height = MAX_HEIGHT,      # px. vertical ROI. Defines frame readout time
            image_width = MAX_WIDTH,        # px. horizontal ROI
            frame_delay_time = 0.0,         # s. optional delay after each frame trigger
            rf_freq = 1e6,                  # RF frequency of AOTF
            led_stack_fraction_on = 1.0,    # percent of time LED is on during every stack acquisition in software_fraction mode
            led_trigger = None,             # "hardware", "software_fraction", "software_time" triggering of LED if light control is desired
            led_time_on = 0.0,              # s. time LED is on during acquisition in software_time mode (i.e. LED period)
            led_frequency = 0):             # pulses/second. Nonzero to pulse the LED for led_time_on at given frequency
        
        if (exposure_time < self.MIN_EXP or exposure_time > self.MAX_EXP):
            raise ValueError("Exposure time is not between 100e-6 and 10.0 sec")
        if (frame_delay_time > self.MAX_DELAY):
            raise ValueError("Delay between frame triggers is greater than 1.0 sec")
        if (image_height > self.MAX_HEIGHT or image_height < self.MIN_HEIGHT):
            raise ValueError("Image height is not between 16 and 2048 pixels")
        if (image_height % 2 != 0):
            raise ValueError("Image height should be an even number of pixels")
        if (image_width > self.MAX_WIDTH or image_width < self.MIN_WIDTH):
            raise ValueError("Image width is not between 40 and 2060 pixels")
        if (z_end < z_start):
            raise ValueError("z_end is smaller than z_start")
        if (z_end > 200 or z_start < -200):
            raise ValueError("z_end and/or z_start are out of range [-200, 200]")
        
        if readout_mode == "fast":
            self.line_time = self.LINE_TIME_FAST
            self.readout_rate = self.READOUT_RATE_FAST
            self.max_full_frame_rate = self.MAX_FRAME_RATE_FAST
        elif readout_mode == "slow":
            self.line_time = self.LINE_TIME_SLOW
            self.readout_rate = self.READOUT_RATE_SLOW
            self.max_full_frame_rate = self.MAX_FRAME_RATE_SLOW
        else:
            raise ValueError("Invalid camera readout mode")
        
        if led_trigger == "hardware":
            print("LED hardware trigger selected. Verify BNC cable connects Cam Exp Out to LED In")
        elif led_trigger == "software_fraction" or led_trigger == "software_time":
            print("LED software trigger selected. Verify BNC cable connects USER1 OUT to LED In")
        elif led_trigger is None:
            print("No LED light control selected.")
        else:
            raise ValueError("Invalid LED trigger mode")
        
        # assign user inputs
        self.num_stacks = num_stacks
        self.stack_delay_time = stack_delay_time
        self.exposure_time = exposure_time
        self.readout_mode = readout_mode
        self.multi_d = multi_d
        self.image_height = image_height
        self.image_width = image_width
        self.frame_delay_time = frame_delay_time
        self.z_start = z_start
        self.z_end = z_end
        self.z_step = z_step
        self.rf_freq = rf_freq
        self.led_fraction_on = led_stack_fraction_on
        self.led_trigger = led_trigger
        self.led_time_on = led_time_on
        self.led_frequency = led_frequency
        
        # conversion from z to galvo voltage according to experimental calibration
        self.volt_per_z = 1.521 / (178.36)
        
        if self.multi_d:
            print("Stage (galvo) control enabled. Verify MicroManager NIDAQHub control is disabled.")
                    

    @property
    def frames_per_stack(self):
        """Get number of frames per stack) start and end inclusive"""
        n = math.floor((self.z_end - self.z_start) / self.z_step) + 1 
        return n if self.multi_d else 1
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

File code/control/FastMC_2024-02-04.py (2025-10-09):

# SPDX-License-Identifier: BSD-3-Clause


import FastMC_core

# -------------------------- Instructions ----------------------------------- #


# This is a script to run high-speed imaging with one or two (simultaneous) PCO Edge cameras and the NI DAQ card.

# It relies on Micro-Manager as an image viewer only.
# Control over the cameras, the stage (galvo), and the LED is done through the NI DAQ card.
# Control over the lasers is hardware-based.

# Although Micro-Manager has no control over the cameras, the imaging parameters have to 
# agree between this script and Micro-Manager to obtain all the images in the viewer.

# The following instructions indicate how to run different types of acquisition.


# ------ 2D, 2 camera imaging: stacks represent the frames to be taken ------ #

#    In this script:
# 1. Set multi_d = False
# 2. Set num_stacks to the number of frames desired
# 3. Set stack_delay_time to the desired delay between frames (not frame_delay_time), if any
# 4. Set any LED control if desired. If using "software_fraction", led_stack_fraction 
#    is the fraction of time the LED is on during each frame. If using "software_time",
#    led pulse width and frequency is independent of frame acquisition
# 5. Set exposure time, image height, and image width to the desired values
# 6. Set the readout mode as "fast" unless you particularly need the camera sensor to read out in slow mode

# 7. Run this script. A window will pop up. If the timing parameters are incorrect,
#    click "Cancel" and modify the parameters above in the script.

# 8. Open Micro-Manager and set: 
#    Core Cam -> Multi Camera
#    Multicam 1  -> pco_camera_1
#    Multicam 1 (trigger mode)  -> External Exp. Ctrl.
#    Multicam 2  -> pco_camera_2
#    Multicam 2 (trigger mode)  -> External Exp. Ctrl.
#    NIDAQ (sequence)  ->  Off

# 9. In Micro-Manager, open "Multi-D Acq":
#    Check "Time Points" and uncheck all other boxes
#    Under "Time Points", set "Counts" to the value of Total number of time points shown in the pop up window
#    Under "Time Points", set "Interval" to the delay between frames (stack_delay_time), if any
#    Check that the time units is seconds (s)

# 10. In Micro-Manager, click "Acquire!"

# 11. Right after, click "OK" in the pop up window




# ------ 3D, 2 camera imaging: stacks represent 3D stacks, frames are the z-slices in each ------ #

#    In this script:
# 1. Set multi_d = True
# 2. Set num_stacks to the number of volumes (3D stacks) desired
# 3. Set stack_delay_time to the desired delay (interval) between 3D stacks
# 4. Set z_start and z_end to the desired start and end of the z stack, and z_step
# 5. Set frame_delay_time to the desired delay between z slices, if any
# 6. Set any LED control if desired. If using "software_fraction", led_stack_fraction 
#    is the fraction of time the LED is on during each 3D stack. If using "software_time",
#    led pulse width and frequency is independent of frame acquisition
# 7. Set exposure time, image height, and image width to the desired values
# 8. Set the readout mode as "fast" unless you particularly need the camera sensor to read out in slow mode

# 9. Run this script. A window will pop up. If the timing parameters are incorrect,
#    click "Cancel" and modify the parameters above in the script.

# 10. Open Micro-Manager and set: 
#    Core Cam -> Multi Camera
#    Multicam 1  -> pco_camera_1
#    Multicam 1 (trigger mode)  -> External Exp. Ctrl.
#    Multicam 2  -> pco_camera_2
#    Multicam 2 (trigger mode)  -> External Exp. Ctrl.
#    NIDAQ (sequence)  ->  Off

# 11. In Micro-Manager, open "Multi-D Acq":
#    Check "Time Points" and uncheck all other boxes
#    Under "Time Points", set "Counts" to the value of Total number of time points shown in the pop up window
#    Under "Time Points", set "Interval" to the delay between frames (stack_delay_time), if any
#    Check that the time units is seconds (s)

# 12. In Micro-Manager, click "Acquire!"

# 13. Right after, click "OK" in the pop up window

# Important: for now, long interval times between stacks might not work with the Micro-Manager viewer



# -------------------------- 1 camera imaging ----------------------------------- #

# In Micro-Manager, set:
#    Core Cam -> pco_camera_1 or pco_camera_2 
#    Multicam 1  -> pco_camera_1
#    Multicam 1 (trigger mode)  -> External Exp. Ctrl.
#    NIDAQ (sequence)  ->  Off

# If Multi-D Acq in Micro-Manager is open, close it and reopen it

# All other steps are the same as above


# -------------------------------- notes ---------------------------------------- #


# You can see acquisition status in Micro-Manager in the home page, next to a yellow bell icon
# that appears while Multi-D Acq is running. 

# If at some point Micro-Manager freezes and does not finish the acquisition, run this script 
# again independently and as many times as needed. This will complete the acquisition in Micro-Manager
# and let you close it and re-start a new one.


# ----------------------------- modify below ------------------------------------ #

scope =  FastMC_core.nidaq(num_stacks = 1,                # number of 3D stacks if multi d, number of frames if not
                             stack_delay_time = 0.0,          # s. time between acquiring any 2 stacks 
                             exposure_time = 200e-3,        # s. effective exposure will be less due to system delay
                             readout_mode = "fast",         # camera readout mode "fast" or "slow"
                             multi_d = True,                # multidimensional acquisition
                             z_start = -75,              # microm. start of z stack. min -178.36 
                             z_end = 75,                 # microm. end of z stack. max 178.36 
                             z_step = 0.52,                  # microm. Step size of galvo scanning
                             image_height = 470,            # px. vertical ROI. Defines frame readout time
                             image_width = 800,            # px. horizontal ROI
                             frame_delay_time = 0.0,        # s. optional delay after each frame trigger
                             led_stack_fraction_on = 0.5,   # percent of time LED is on during every stack acquisition in software_fraction mode
                             led_trigger = "hardware", # "hardware", "software_fraction", "software_time" triggering of LED if light control is desired
                             led_time_on = 1,               # s. time LED is on during acquisition in software_time mode (i.e. LED period)
                             led_frequency = 1/3)           # pulses/second. Nonzero to pulse the LED for led_time_on at given frequency

# -------------------------- do not modify below --------------------------------- #

scope.acquire()
